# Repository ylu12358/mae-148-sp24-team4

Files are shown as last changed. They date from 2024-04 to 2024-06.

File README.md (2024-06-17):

# MAE 148 SP24 Team 4

## Premise
SortBot is an autonomous vehicle that delivers items from one pickup point to different drop off locations.

## CAD
All parts modeled in Solidworks

## Schematic
Generated using LaTeX
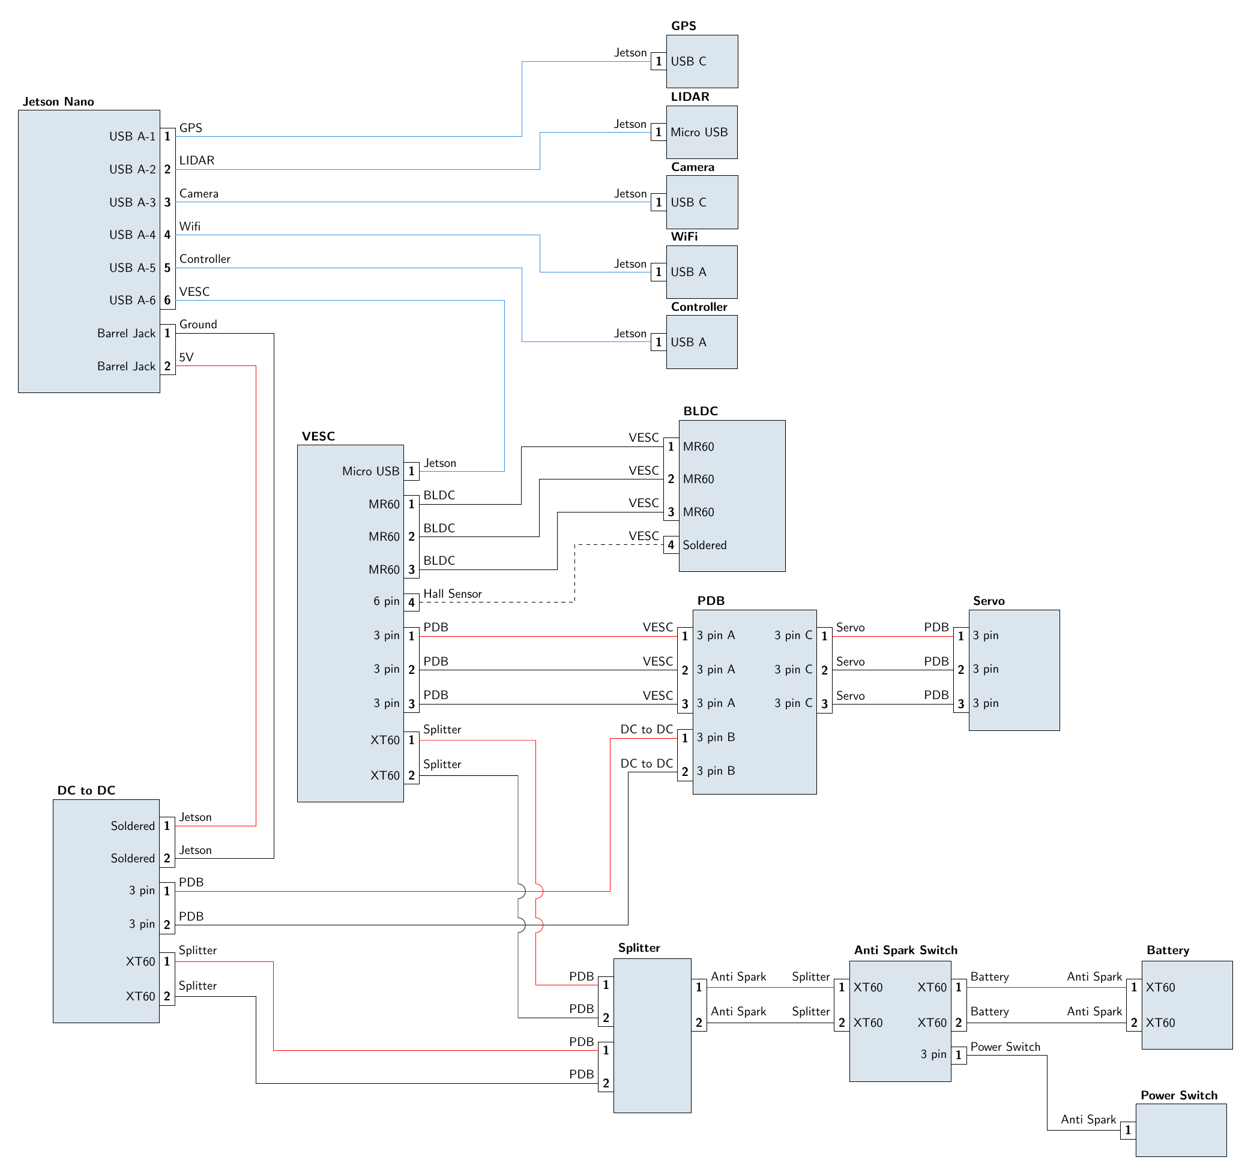
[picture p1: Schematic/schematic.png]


## Software
Shape detection AI model
Path optimization
GPS navigation

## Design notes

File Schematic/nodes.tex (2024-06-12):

\documentclass[border=5mm]{standalone}
\usepackage{tikz}
\usetikzlibrary{calc}           % For general calculations
\usetikzlibrary{matrix}         % For the matrix cmd
\usetikzlibrary{positioning}    % For above = Xcm of and similars
\usetikzlibrary{intersections}  % Mainly here for the arc over line
\usetikzlibrary{topaths}        % Enable move to operation
\usetikzlibrary{backgrounds}    % Put colors in background
\usetikzlibrary{shapes}         % Allow use of more shapes

\tikzset{rosnode/.style={ellipse,
                        fill=blue!20,
                        matrix of nodes,
                        row sep=1mm,
                        column sep=1mm,
                        nodes={anchor=center, inner sep=0pt, outer sep=0pt}
                        },
        rostopic/.style={ellipse,
                        fill=blue!50,
                        matrix of nodes,
                        row sep=1mm,
                        column sep=1mm,
                        nodes={anchor=center, inner sep=0pt, outer sep=0pt}
        },
}

\begin{document}
\sffamily

\begin{tikzpicture}
    [scale=.9,auto=center]

    % EXAMPLE
    \matrix[rosnode] (exampleA) {
        exampleA node \\
    };

    \matrix[rostopic, right= of exampleA] (exampleC) {
        example topic \\
    };

    \matrix[rosnode, right= of exampleC] (exampleB) {
        exampleB node \\
    };
    
    \draw[->,orange,line width=1pt] (exampleA) -- (exampleC);
    \draw[->,green,line width=1pt] (exampleC) -- (exampleB);

    % NODE DIAGRAM
    \matrix[rosnode, below right= 5cm of exampleC] (detection) {
        detection node \\
        \parbox{3.6cm}{Detects shapes, spits out a string corresponding to which dropoff locations need to be visited} \\
    };

    \matrix[rostopic, below= of detection] (dropoff) {
        dropoff topic \\
        String of dropoff locations \\
    };

    \matrix[rosnode, below= of dropoff] (pathCreation) {
        pathCreation node \\
    };

    \matrix[rostopic, below left= of pathCreation] (path) {
        path topic \\
        \parbox{3cm}{Contains csv file of GPS coordinates} \\
    };

    \matrix[rostopic, right= of path] (status) {
        status topic \\
        \parbox{4cm}{Contains or doesn't contain signal that path creation is done} \\
    };

    \matrix[rosnode, below= of status] (donkeyProcessing) {
        donkeyProcessing node \\
        \parbox{4cm}{Starts donkeycar, resets the origin, sets mode to autosteer only} \\
    };

    \matrix[rosnode, left= of donkeyProcessing] (donkeycar) {
        donkeycar "node" \\
        Good ole donkeycar \\
    };

    \matrix[rosnode, left= of donkeycar] (throttleProcessing) {
        throttleProcessing node \\
        \parbox{4.5cm}{Takes in GPS data, calculates distance from current position to next dropoff point, sets donkeycar to either full auto or steering only (off)} \\
    };

    \matrix[rostopic, above= of throttleProcessing] (GPSdata) {
        GPSdata topic \\
        Reports current GPS data \\
    };

    \matrix[rosnode, above= of GPSdata] (GPS) {
        GPS node \\
        \parbox{4cm}{Spits out serial data from GPS} \\
    };
    
    \draw[->,orange,line width=1pt] (detection) -- (dropoff);
    \draw[->,green,line width=1pt] (dropoff) -- (pathCreation);
    \draw[->,orange,line width=1pt] (pathCreation) -- (path);
    \draw[->,orange,line width=1pt] (pathCreation) -- (status);
    \draw[->,green,line width=1pt] (status) -- (donkeyProcessing);

    \draw[->,blue,line width=1pt] (path) -- (donkeycar);
    \draw[->,blue,line width=1pt] (donkeyProcessing) -- (donkeycar);
    \draw[->,blue,line width=1pt] (throttleProcessing) -- (donkeycar);

    \draw[->,orange,line width=1pt] (GPS) -- (GPSdata);
    \draw[->,green,line width=1pt] (GPSdata) -- (throttleProcessing);
    \draw[->,green,line width=1pt] (path) -- (throttleProcessing);
    
\end{tikzpicture}
\end{document}

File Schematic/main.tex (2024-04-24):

\documentclass[border=5mm]{standalone}
\usepackage{tikz}
\usetikzlibrary{calc}           % For general calculations
\usetikzlibrary{matrix}         % For the matrix cmd
\usetikzlibrary{positioning}    % For above = Xcm of and similars
\usetikzlibrary{intersections}  % Mainly here for the arc over line
\usetikzlibrary{topaths}        % Enable move to operation
\usetikzlibrary{backgrounds}    % Put colors in background

%%% Sourced from https://tex.stackexchange.com/questions/241357/wiring-diagrams-with-pinout
%%% Adapted from https://tex.stackexchange.com/a/111674/114143
%%% provides syntax for jumping lines
\tikzset{
    connect/.style args={(#1) to (#2) over #3 by #4}{
        insert path={
            \pgfextra{
                \pgfinterruptpath
                    \path [name path=userpath] (#1) -- (#2);
                    \path [name intersections={of=userpath and #3,by=overpoint}];
                \endpgfinterruptpath                
            }
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
                                       column 2/.style={font=\bfseries}
                                       },
        camera/.style={column 1/.style={nodes={above left}},
                                       column 3/.style={nodes={right}},
                                       column 2/.style={font=\bfseries}
                                       },
        wifi/.style={column 1/.style={nodes={above left}},
                                       column 3/.style={nodes={right}},
                                       column 2/.style={font=\bfseries}
                                       },
        controller/.style={column 1/.style={nodes={above left}},
                                       column 3/.style={nodes={right}},
                                       column 2/.style={font=\bfseries}
                                       },
        vesc/.style={column 1/.style={nodes={left}},
                                       column 3/.style={nodes={above right}},
                                       column 2/.style={font=\bfseries}
                                       },
        pdbL/.style={column 1/.style={nodes={above left}},
                                       column 3/.style={nodes={right}},
                                       column 2/.style={font=\bfseries}
                                       },
        pdbR/.style={column 1/.style={nodes={left}},
                                       column 3/.style={nodes={above right}},
                                       column 2/.style={font=\bfseries}
                                       },
        bldc/.style={column 1/.style={nodes={above left}},
                                       column 3/.style={nodes={right}},
                                       column 2/.style={font=\bfseries}
                                       },
        dc2dc/.style={column 1/.style={nodes={left}},
                                       column 3/.style={nodes={above right}},
                                       column 2/.style={font=\bfseries}
                                       },
        splitterL/.style={column 1/.style={nodes={above left}},
                                       column 3/.style={nodes={right}},
                                       column 2/.style={font=\bfseries}
                                       },
        splitterR/.style={column 1/.style={nodes={left}},
                                       column 3/.style={nodes={above right}},
                                       column 2/.style={font=\bfseries}
                                       },
        antisparkL/.style={column 1/.style={nodes={above left}},
                                       column 3/.style={nodes={right}},
                                       column 2/.style={font=\bfseries}
                                       },
        antisparkR/.style={column 1/.style={nodes={left}},
                                       column 3/.style={nodes={above right}},
                                       column 2/.style={font=\bfseries}
                                       },
        servo/.style={column 1/.style={nodes={above left}},
                                       column 3/.style={nodes={right}},
                                       column 2/.style={font=\bfseries}
                                       },
        battery/.style={column 1/.style={nodes={above left}},
                                       column 3/.style={nodes={right}},
                                       column 2/.style={font=\bfseries}
                                       },
        power/.style={column 1/.style={nodes={above left}},
                                       column 3/.style={nodes={right}},
                                       column 2/.style={font=\bfseries}
                                       },
}

%% Colors
\definecolor{beaublue}{rgb}{0.86, 0.9, 0.93}
\definecolor{usbblue}{rgb}{0.19, 0.55, 0.91}

\begin{document}
\sffamily
\begin{tikzpicture}
%% Drawing the first block (jetson)
    \matrix[wire board,jetson] (jetson) {
        USB A-1     &   1   &   GPS         \\
        USB A-2     &   2   &   LIDAR       \\
        USB A-3     &   3   &   Camera      \\
        USB A-4     &   4   &   Wifi        \\
        USB A-5     &   5   &   Controller  \\
        USB A-6     &   6   &   VESC        \\
        Barrel Jack &   1   &   Ground      \\
        Barrel Jack &   2   &   5V          \\
    };
    \draw (jetson-1-2.north east) rectangle (jetson-6-2.south west); % USB
    \draw (jetson-7-2.north east) rectangle (jetson-8-2.south west); % Barrel Jack
    \scoped[on background layer]{\draw [fill=beaublue] (jetson-1-2.north west)+(-4cm,0.5cm) node[above right, font=\bfseries]{Jetson Nano} rectangle ($(jetson-8-2.south west)+(0,-0.5cm)$);}

%% GPS
    \matrix[wire board, gps, matrix anchor=south, above right=1.151cm and 14cm of jetson.north] (gps) {
        Jetson  &   1   &   USB C \\
    };
    \draw (gps-1-2.north east) rectangle (gps-1-2.south west); % USB
    \scoped[on background layer]{\draw [fill=beaublue] (gps-1-2.north east)+(0cm,0.5cm) node[above right, align=center, font=\bfseries]{GPS} rectangle ($(gps-1-2.south east)+(2cm,-0.5cm)$);}

%% LIDAR
    \matrix[wire board, lidar, matrix anchor=south, below right=2cm and 0.3cm of gps.south] (lidar) {
        Jetson  &   1   &   Micro USB \\
    };
    \draw (lidar-1-2.north east) rectangle (lidar-1-2.south west); % USB
    \scoped[on background layer]{\draw [fill=beaublue] (lidar-1-2.north east)+(0cm,0.5cm) node[above right, align=center, font=\bfseries]{LIDAR} rectangle ($(lidar-1-2.south east)+(2cm,-0.5cm)$);}

%% Camera
    \matrix[wire board, camera, matrix anchor=north, below left=1cm and 0.3cm of lidar.south] (camera) {
        Jetson  &   1   &   USB C \\
    };
    \draw (camera-1-2.north east) rectangle (camera-1-2.south west); % USB
    \scoped[on background layer]{\draw [fill=beaublue] (camera-1-2.north east)+(0cm,0.5cm) node[above right, align=center, font=\bfseries]{Camera} rectangle ($(camera-1-2.south east)+(2cm,-0.5cm)$);}

%% Wifi
    \matrix[wire board, wifi, matrix anchor=north, below=1cm of camera.south] (wifi) {
        Jetson  &   1   &   USB A \\
    };
    \draw (wifi-1-2.north east) rectangle (wifi-1-2.south west); % USB
    \scoped[on background layer]{\draw [fill=beaublue] (wifi-1-2.north east)+(0cm,0.5cm) node[above right, align=center, font=\bfseries]{WiFi} rectangle ($(wifi-1-2.south east)+(2cm,-0.5cm)$);}

%% Controller
    \matrix[wire board, controller, matrix anchor=north, below=1cm of wifi.south] (controller) {
        Jetson  &   1   &   USB A \\
    };
    \draw (controller-1-2.north east) rectangle (controller-1-2.south west); % USB
    \scoped[on background layer]{\draw [fill=beaublue] (controller-1-2.north east)+(0cm,0.5cm) node[above right, align=center, font=\bfseries]{Controller} rectangle ($(controller-1-2.south east)+(2cm,-0.5cm)$);}

%% VESC
    \matrix[wire board, vesc, matrix anchor=north, below right=2cm and 7cm of jetson.south] (vesc) {
        Micro USB   &   1   &   Jetson      \\
        MR60        &   1   &   BLDC        \\
        MR60        &   2   &   BLDC        \\
        MR60        &   3   &   BLDC        \\
        6 pin       &   4   &   Hall Sensor \\
        3 pin       &   1   &   PDB         \\
        3 pin       &   2   &   PDB         \\
        3 pin       &   3   &   PDB         \\
        XT60        &   1   &   Splitter    \\
        XT60        &   2   &   Splitter    \\
    };
    \draw (vesc-1-2.north east) rectangle (vesc-1-2.south west); % USB
    \draw (vesc-2-2.north east) rectangle (vesc-4-2.south west); % BLDC
    \draw (vesc-5-2.north east) rectangle (vesc-5-2.south west); % Hall Sensor
    \draw (vesc-6-2.north east) rectangle (vesc-8-2.south west); % PDB
    \draw (vesc-9-2.north east) rectangle (vesc-10-2.south west); % splitterL
    \scoped[on background layer]{\draw [fill=beaublue] (vesc-1-2.north west)+(-3cm,0.5cm) node[above right, align=center, font=\bfseries]{VESC} rectangle ($(vesc-10-2.south west)+(0cm,-0.5cm)$);}

%% BLDC
    \matrix[wire board, bldc, matrix anchor=north, above right=.7cm and 7.5cm of vesc.north] (bldc) {
        VESC  &   1   & MR60        \\
        VESC  &   2   & MR60        \\
        VESC  &   3   & MR60        \\
        VESC  &   4   & Soldered    \\
    };
    \draw (bldc-1-2.north east) rectangle (bldc-3-2.south west); % VESC
    \draw (bldc-4-2.north east) rectangle (bldc-4-2.south west); % Hall Sensor
    \scoped[on background layer]{\draw [fill=beaublue] (bldc-1-2.north east)+(0cm,0.5cm) node[above right, align=center, font=\bfseries]{BLDC} rectangle ($(bldc-4-2.south east)+(3cm,-0.5cm)$);}

%% PDB
    \matrix[wire board, pdbL, matrix anchor=north, below=1.6069cm of bldc.south] (pdbL) {
        VESC        &   1   &   3 pin A \\
        VESC        &   2   &   3 pin A \\
        VESC        &   3   &   3 pin A \\
        DC to DC    &   1   &   3 pin B \\
        DC to DC    &   2   &   3 pin B \\
    };
    \matrix[wire board, pdbR, matrix anchor=north, right=4cm of pdbL.north] (pdbR) {
        3 pin C &   1   &   Servo   \\
        3 pin C &   2   &   Servo   \\
        3 pin C &   3   &   Servo   \\
    };
    \draw (pdbL-1-2.north east) rectangle (pdbL-3-2.south west); % VESC
    \draw (pdbL-4-2.north east) rectangle (pdbL-5-2.south west); % DC to DC
    \draw (pdbR-1-2.north east) rectangle (pdbR-3-2.south west); % Servo
    \scoped[on background layer]{\draw [fill=beaublue] (pdbL-1-2.north east)+(0cm,0.5cm) node[above right, align=center, font=\bfseries]{PDB} rectangle ($(pdbR-3-2.south west)+(0cm,-2.3cm)$);}

%% Servo
    \matrix[wire board, servo, matrix anchor=north, right=4cm of pdbR.north] (servo) {
        PDB     &   1   &   3 pin   \\
        PDB     &   2   &   3 pin   \\
        PDB     &   3   &   3 pin   \\
    };
    \draw (servo-1-2.north east) rectangle (servo-3-2.south west); % PDB
    \scoped[on background layer]{\draw [fill=beaublue] (servo-1-2.north east)+(0cm,0.5cm) node[above right, align=center, font=\bfseries]{Servo} rectangle ($(servo-3-2.south west)+(3cm,-0.5cm)$);}

%% DC to DC
    \matrix[wire board, dc2dc, matrix anchor=north, below=12cm of jetson.south] (dc2dc) {
        Soldered    &   1   &   Jetson      \\
        Soldered    &   2   &   Jetson      \\
        3 pin       &   1   &   PDB         \\
        3 pin       &   2   &   PDB         \\
        XT60        &   1   &   Splitter    \\
        XT60        &   2   &   Splitter    \\
    };
    \draw (dc2dc-1-2.north east) rectangle (dc2dc-2-2.south west); % Jetson
    \draw (dc2dc-3-2.north east) rectangle (dc2dc-4-2.south west); % splitterL
    \draw (dc2dc-5-2.north east) rectangle (dc2dc-6-2.south west); % PDB
    \scoped[on background layer]{\draw [fill=beaublue] (dc2dc-1-2.north west)+(-3cm,0.5cm) node[above right, align=center, font=\bfseries]{DC to DC} rectangle ($(dc2dc-6-2.south west)+(0cm,-0.5cm)$);}

%% Splitter
    \matrix[wire board, splitterL, matrix anchor=north, below left=5cm and 2.5cm of pdbL.south] (splitterL) {
        PDB     &   1   &   \\
        PDB     &   2   &   \\
        PDB     &   1   &   \\
        PDB     &   2   &   \\
    };
    \matrix[wire board, splitterR, matrix anchor=north, right=4cm of splitterL.north] (splitterR) {
                &   1   &   Anti Spark  \\
                &   2   &   Anti Spark  \\
    };
    \draw (splitterL-1-2.north east) rectangle (splitterL-2-2.south west); % VESC
    \draw (splitterL-3-2.north east) rectangle (splitterL-4-2.south west); % DC to DC
    \draw (splitterR-1-2.north east) rectangle (splitterR-2-2.south west); % Anti Spark
    \scoped[on background layer]{\draw [fill=beaublue] (splitterL-1-2.north east)+(0cm,0.5cm) node[above right, align=center, font=\bfseries]{Splitter} rectangle ($(splitterR-2-2.south west)+(0cm,-2.3cm)$);}

%% Anti Spark Switch
    \matrix[wire board, antisparkL, matrix anchor=north, right=3cm of splitterR.north] (antisparkL) {
        Splitter    &   1   &   XT60    \\
        Splitter    &   2   &   XT60    \\
    };
    \matrix[wire board, antisparkR, matrix anchor=north, right=4cm of antisparkL.north] (antisparkR) {
        XT60    &   1   &   Battery         \\
        XT60    &   2   &   Battery         \\
        3 pin   &   1   &   Power Switch    \\
    };
    \draw (antisparkL-1-2.north east) rectangle (antisparkL-2-2.south west); % Splitter
    \draw (antisparkR-1-2.north east) rectangle (antisparkR-2-2.south west); % Battery
    \draw (antisparkR-3-2.north east) rectangle (antisparkR-3-2.south west); % Power Switch
    \scoped[on background layer]{\draw [fill=beaublue] (antisparkL-1-2.north east)+(0cm,0.5cm) node[above right, align=center, font=\bfseries]{Anti Spark Switch} rectangle ($(antisparkR-3-2.south west)+(0cm,-0.5cm)$)};

%% Battery
    \matrix[wire board, battery, matrix anchor=north, right=4cm of antisparkR.north] (battery) {
        Anti Spark    &   1   &   XT60    \\
        Anti Spark    &   2   &   XT60    \\
    };
    \draw (battery-1-2.north east) rectangle (battery-2-2.south west); % Anti Spark
    \scoped[on background layer]{\draw [fill=beaublue] (battery-1-2.north east)+(0cm,0.5cm) node[above right, align=center, font=\bfseries]{Battery} rectangle ($(battery-2-2.south west)+(3cm,-0.5cm)$);}

%% Power Switch
    \matrix[wire board, power, matrix anchor=north, below left=2cm and .7cm of battery.south] (power) {
        Anti Spark    &   1   &     \\
    };
    \draw (power-1-2.north east) rectangle (power-1-2.south west); % Anti Spark
    \scoped[on background layer]{\draw [fill=beaublue] (power-1-2.north east)+(0cm,0.5cm) node[above right, align=center, font=\bfseries]{Power Switch} rectangle ($(power-1-2.south west)+(3cm,-0.5cm)$);}

%% Wires
    \draw [usbblue] (jetson-1-2) -- +(10.0cm,0) |- (gps-1-2);
    \draw [usbblue] (jetson-2-2) -- +(10.5cm,0) |- (lidar-1-2);
    \draw [usbblue] (jetson-3-2) -- +(10.5cm,0) |- (camera-1-2);
    \draw [usbblue] (jetson-4-2) -- +(10.5cm,0) |- (wifi-1-2);
    \draw [usbblue] (jetson-5-2) -- +(10.0cm,0) |- (controller-1-2);
    
    \draw [usbblue] (jetson-6-2) -- +(9.5cm,0) |- (vesc-1-2);

    \draw (jetson-7-2) -- +(3.0cm,0) |- (dc2dc-2-2);
    \draw [red] (jetson-8-2) -- +(2.5cm,0) |- (dc2dc-1-2);
    
    \draw (vesc-2-2) -- +(3.1cm,0) |- (bldc-1-2);
    \draw (vesc-3-2) -- +(3.6cm,0) |- (bldc-2-2);
    \draw (vesc-4-2) -- +(4.1cm,0) |- (bldc-3-2);
    \draw [dashed] (vesc-5-2) -- +(4.6cm,0) |- (bldc-4-2);

    \draw [red] (vesc-6-2) -- +(4.5cm,0) |- (pdbL-1-2);
    \draw (vesc-7-2) -- +(4.0cm,0) |- (pdbL-2-2);
    \draw (vesc-8-2) -- +(3.5cm,0) |- (pdbL-3-2);

    \draw [red] [name path=horiz1] (dc2dc-3-2) -- +(12.5cm,0) |- (pdbL-4-2);
    \draw [name path=horiz2] (dc2dc-4-2) -- +(13.0cm,0) |- (pdbL-5-2);
    
    \draw [red] (pdbR-1-2) -- +(0.5cm,0) |- (servo-1-2);
    \draw (pdbR-2-2) -- +(0.5cm,0) |- (servo-2-2);
    \draw (pdbR-3-2) -- +(0.5cm,0) |- (servo-3-2);

    \path [name path=over1](vesc-9-2) -- +(3.5cm,0) node[coordinate](A1){} |- node[pos=.34,coordinate](A2){} node[coordinate](A3){} (splitterL-1-2);
    \draw [red] [connect={(A1) to (A2) over horiz1 by -6pt}] (vesc-9-2) -- (A1);
    \draw [red] [connect={(A2) to (A3) over horiz2 by -6pt}] (A3) -- (splitterL-1-2);
    
    \path [name path=over1](vesc-10-2) -- +(3.0cm,0) node[coordinate](B1){} |- node[pos=.29,coordinate](B2){} node[coordinate](B3){} (splitterL-2-2);
    \draw [connect={(B1) to (B2) over horiz1 by -6pt}] (vesc-10-2) -- (B1);
    \draw [connect={(B2) to (B3) over horiz2 by -6pt}] (B3) -- (splitterL-2-2);
    
    \draw [red] (dc2dc-5-2) -- +(3.0cm,0) |- (splitterL-3-2);
    \draw (dc2dc-6-2) -- +(2.5cm,0) |- (splitterL-4-2);

    \draw [red] (splitterR-1-2) -- +(0.5cm,0) |- (antisparkL-1-2);
    \draw (splitterR-2-2) -- +(0.5cm,0) |- (antisparkL-2-2);

    \draw [red](antisparkR-1-2) -- +(0.5cm,0) |- (battery-1-2);
    \draw (antisparkR-2-2) -- +(0.5cm,0) |- (battery-2-2);
    \draw (antisparkR-3-2) -- +(2.5cm,0) |- (power-1-2);

\end{tikzpicture}                                          
\end{document}

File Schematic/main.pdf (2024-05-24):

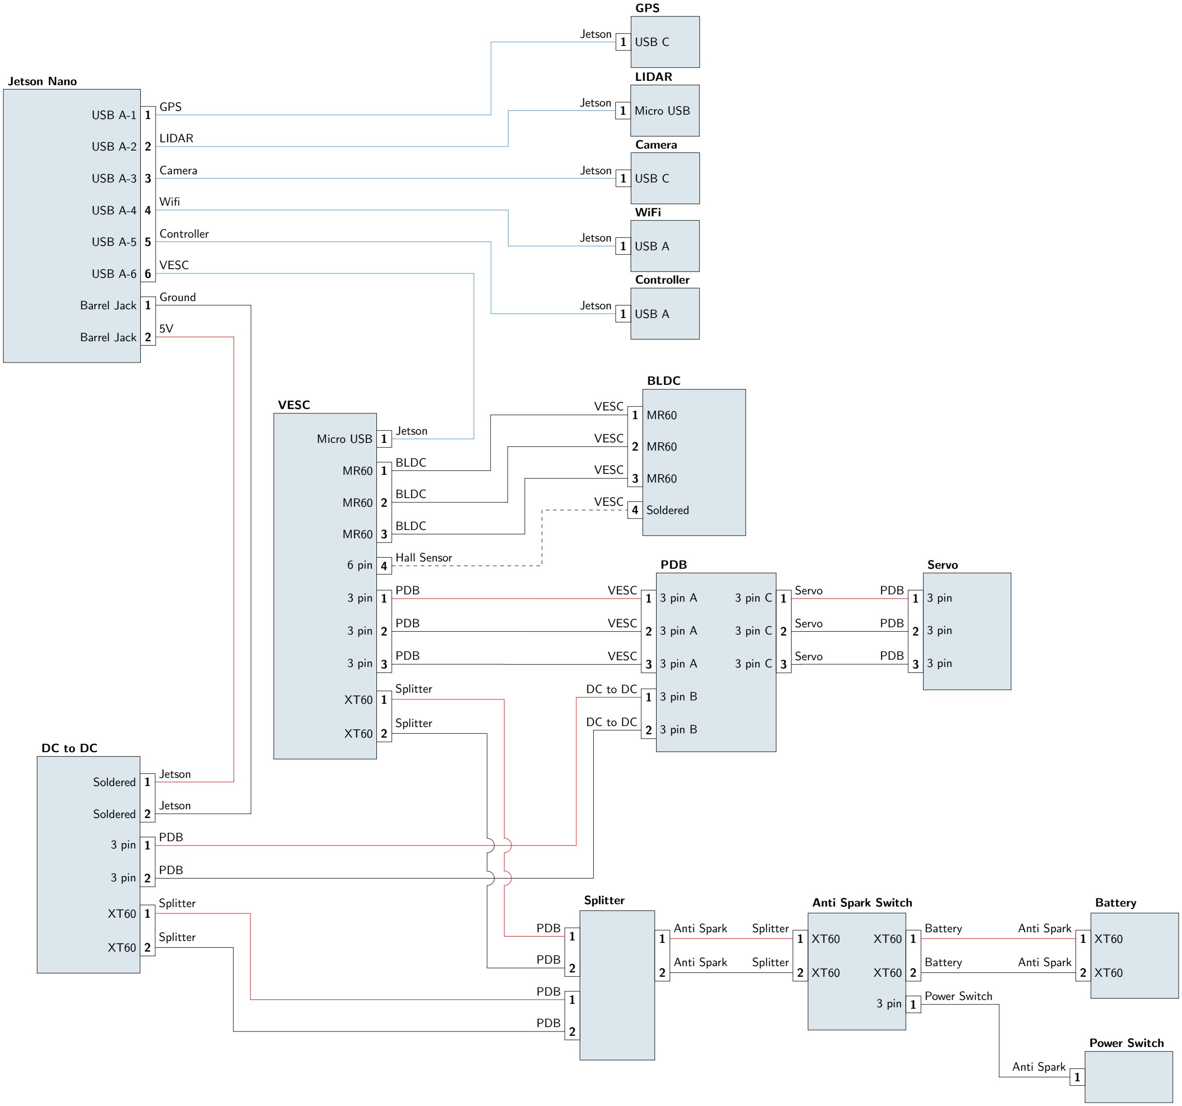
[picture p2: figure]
Jetson Nano; GPS; LIDAR; Camera; WiFi; Controller; VESC; BLDC; PDB; Servo; Splitter; Anti Spark Switch; Battery; Power Switch; USB A-1; USB A-2; USB A-3; USB A-4; Wifi; USB A-5; USB A-6; Barrel Jack; Ground; Jetson; USB C; Micro USB; USB A; 6 pin; Hall Sensor; 3 pin; 4 Soldered; 3 pin A; 3 pin B; 3 pin C; Soldered; Anti Spark

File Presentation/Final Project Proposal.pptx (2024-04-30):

## Project Proposal

- ECE MAE 148 Team 4| April 30, 2024

Yuanyang Lu, Miles Puchner, Alex La, David Deharo

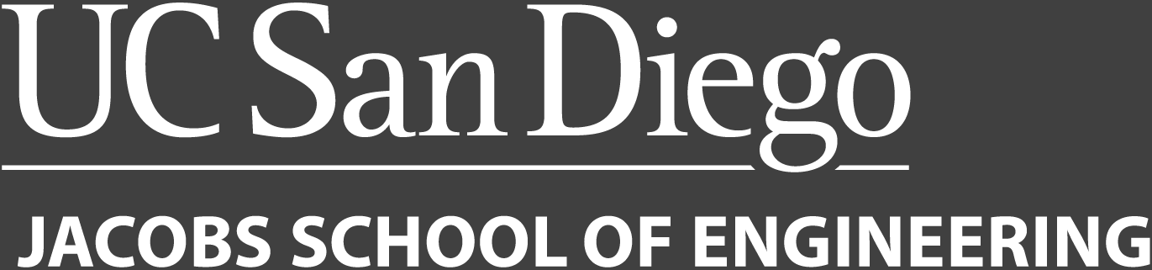
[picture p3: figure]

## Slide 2

ECE MAE 148 Team 4

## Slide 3

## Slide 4

## Thank you!

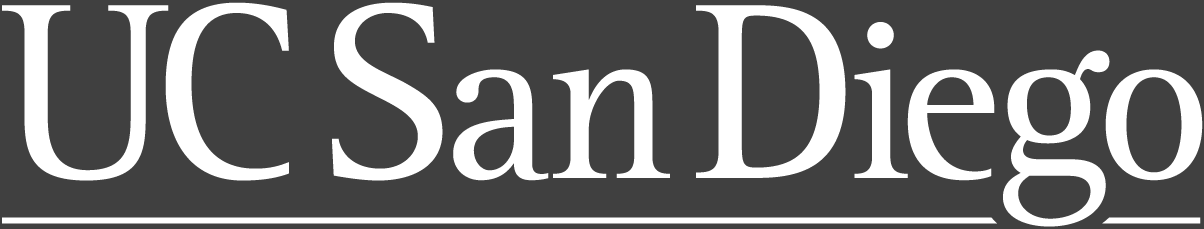
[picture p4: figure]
UC San Diego Logo

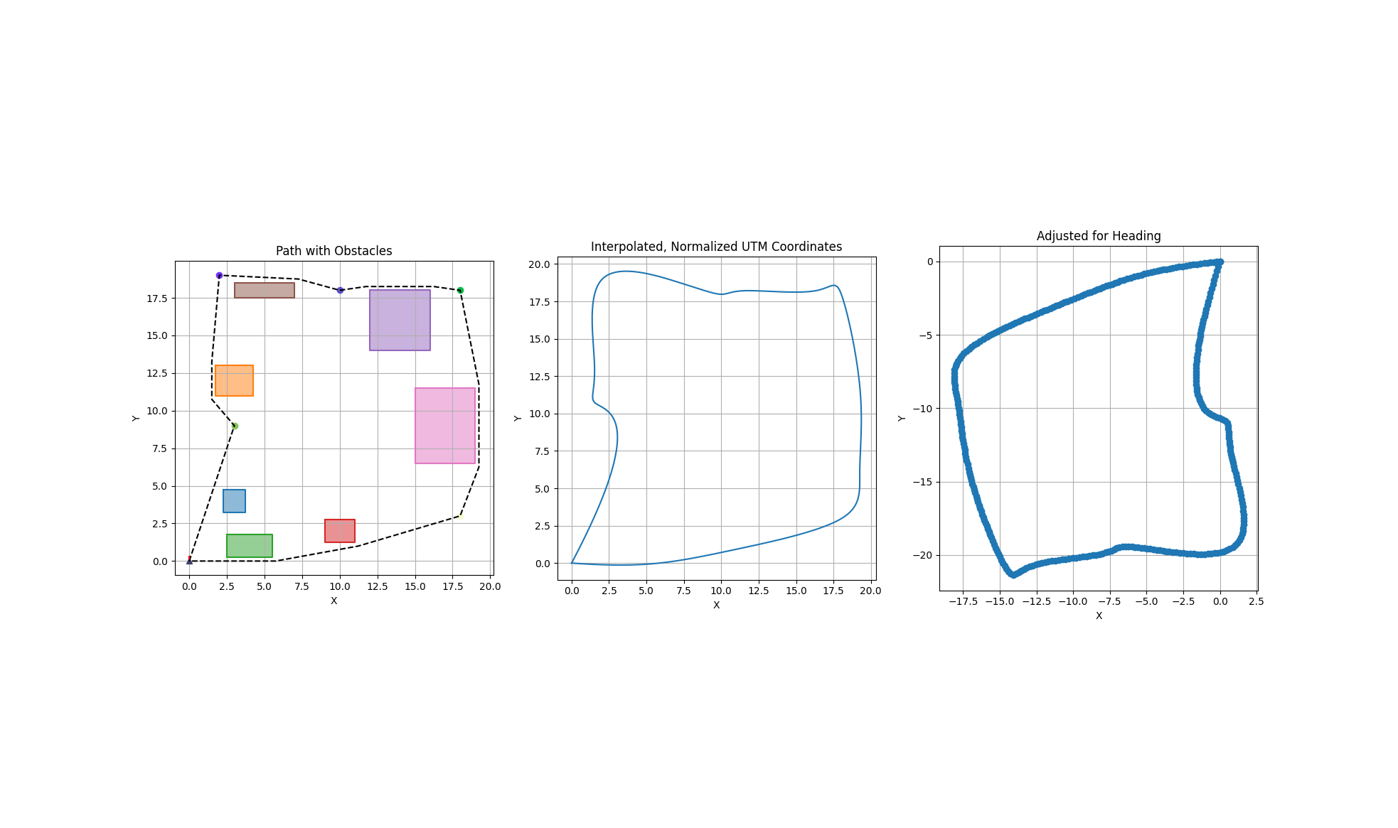
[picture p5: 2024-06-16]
Presentation/Figure_3.png

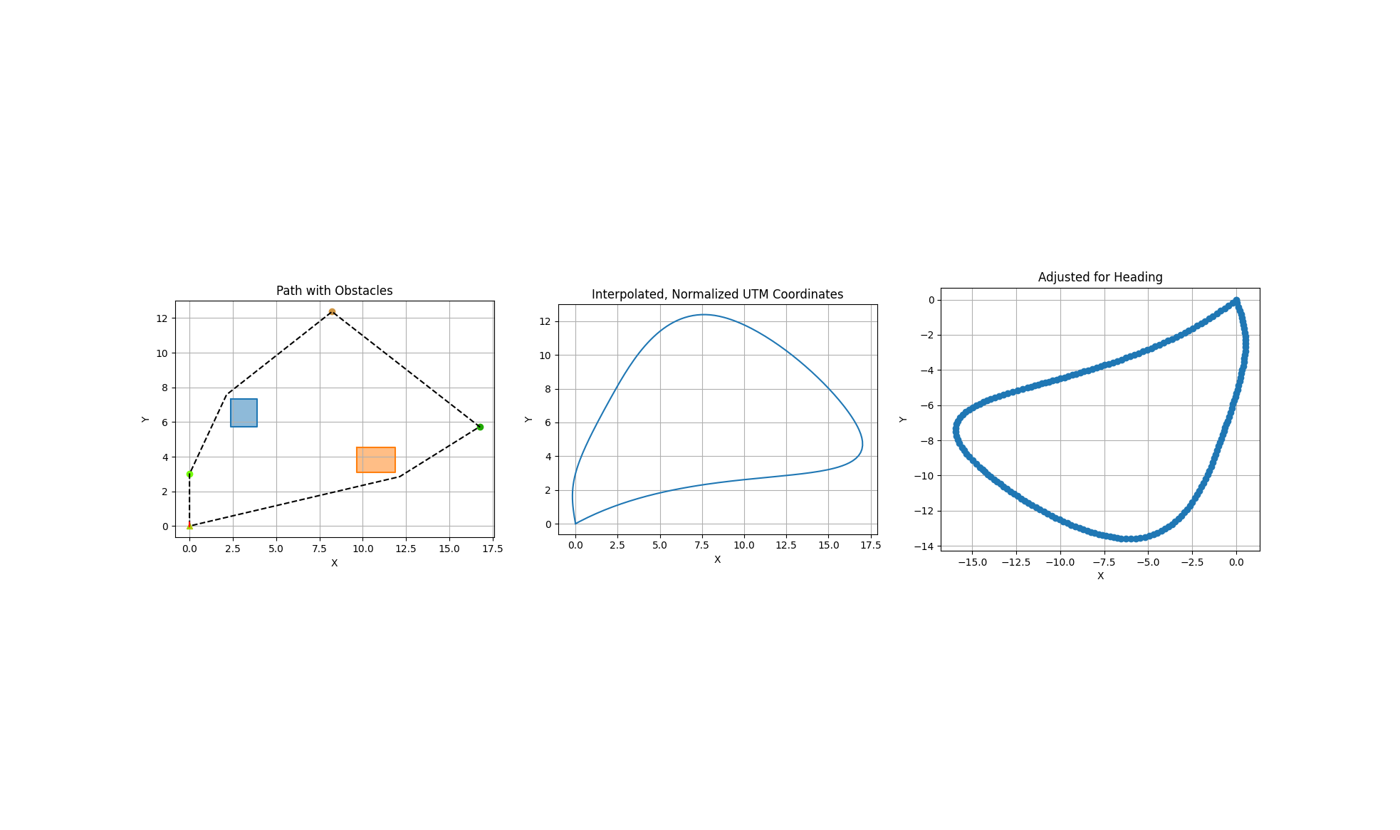
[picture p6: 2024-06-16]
Presentation/Figure_2.png

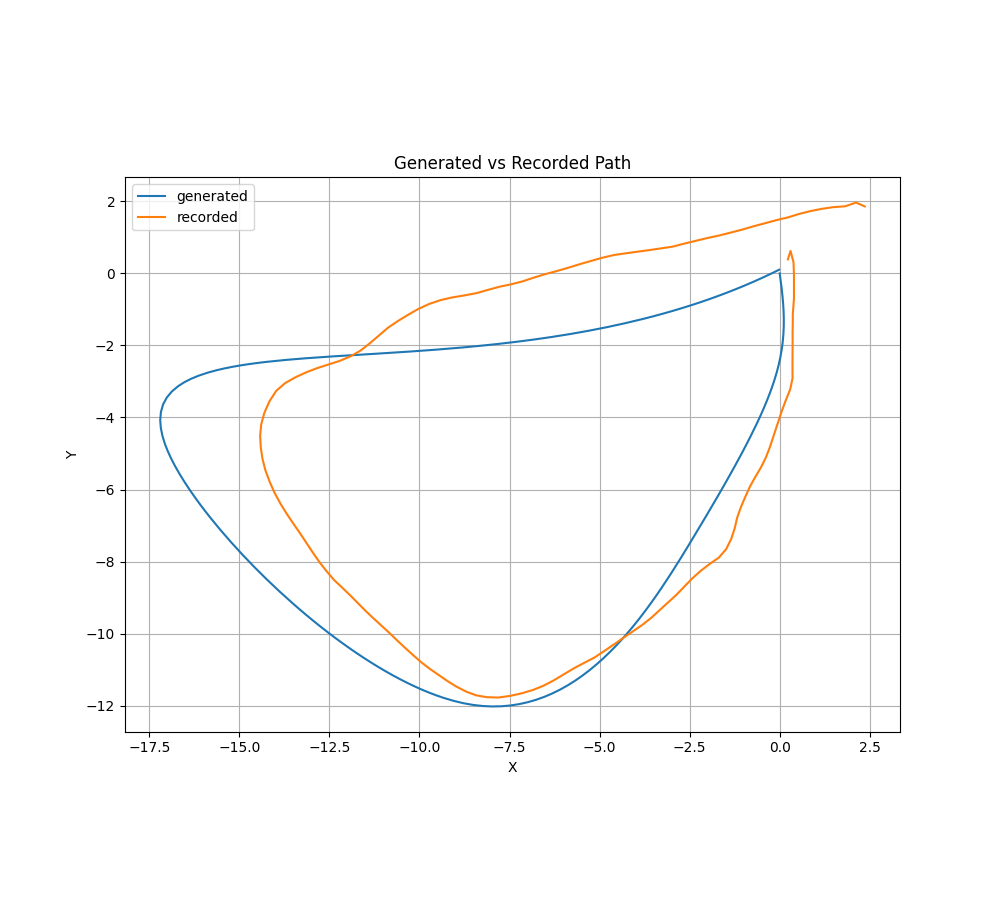
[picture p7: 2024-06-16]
Presentation/Figure_1.png

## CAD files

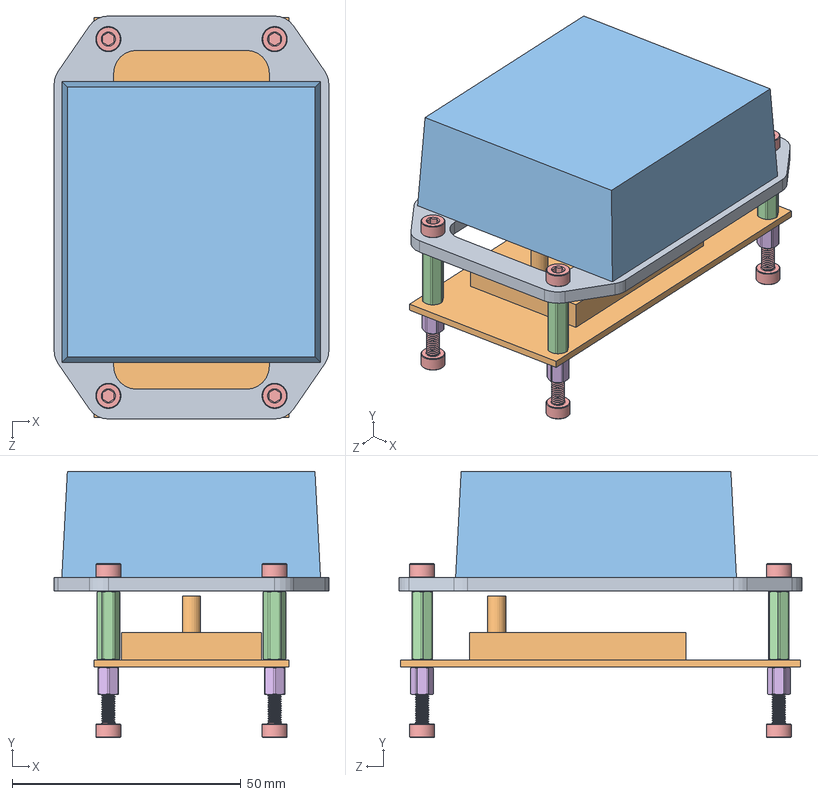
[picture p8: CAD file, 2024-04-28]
CAD/GPS/GPS Assembly.SLDASM
60.0 x 58.1 x 88.0 mm
GPS Bracket
GPS
GPS Antenna
94868A722_Female Threaded Hex Standoff x 4
91290A113_Alloy Steel Socket Head Screw x 8
93655A093_Male-Female Threaded Hex Standoff x 4

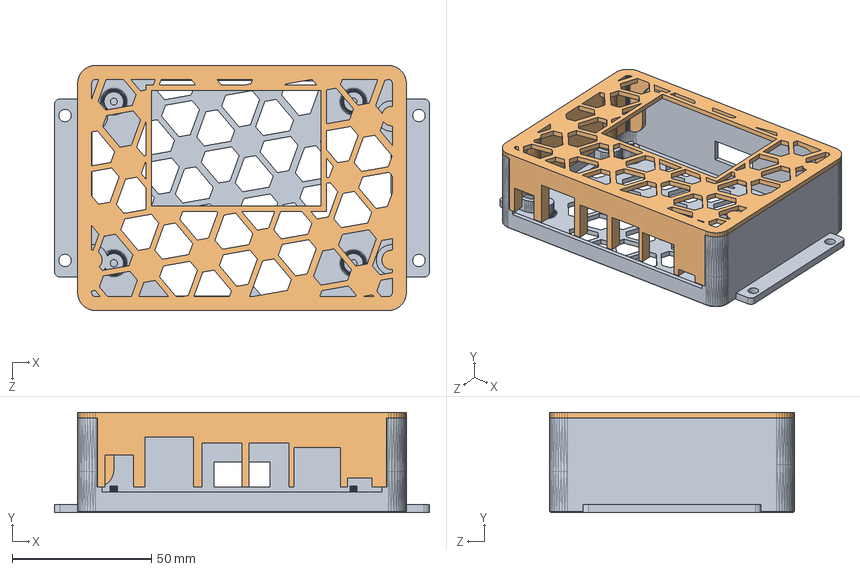
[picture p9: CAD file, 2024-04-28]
CAD/Jetson/Jetson.SLDASM
134.6 x 36.0 x 88.0 mm
Case Bottom
Case Top

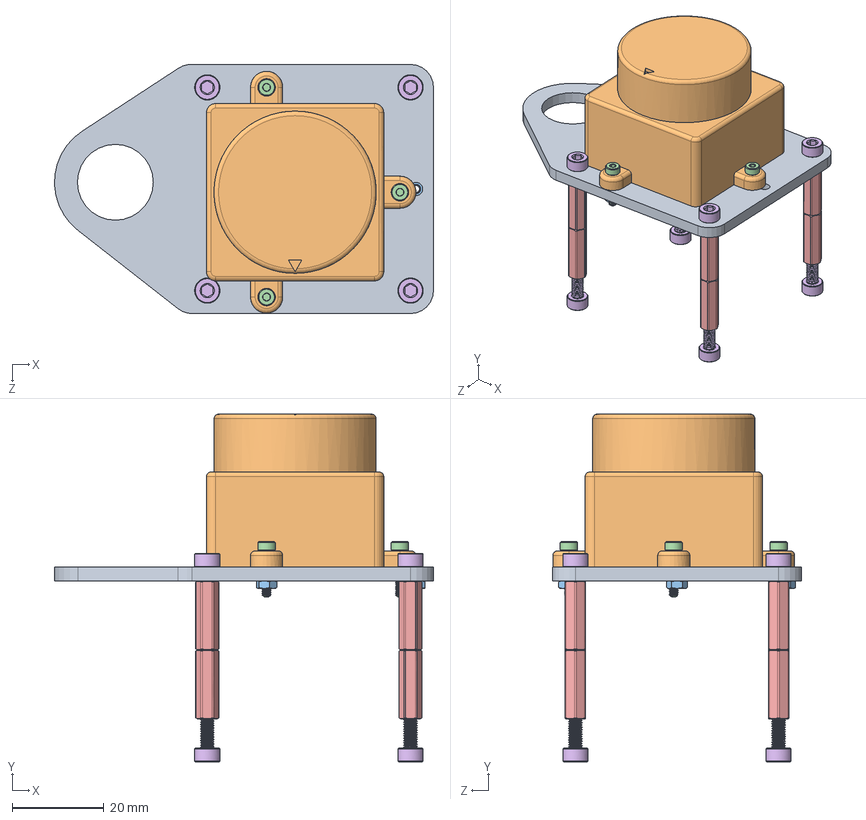
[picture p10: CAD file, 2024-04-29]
CAD/LIDAR/LIDAR Assembly.SLDASM
82.4 x 75.7 x 54.2 mm
LIDAR Mount
LIDAR
90591A265_Zinc-Plated Steel Hex Nut x 3
91292A833_18-8 Stainless Steel Socket Head Screw x 3
94868A722_Female Threaded Hex Standoff (1) x 8
91290A113_Alloy Steel Socket Head Screw x 8

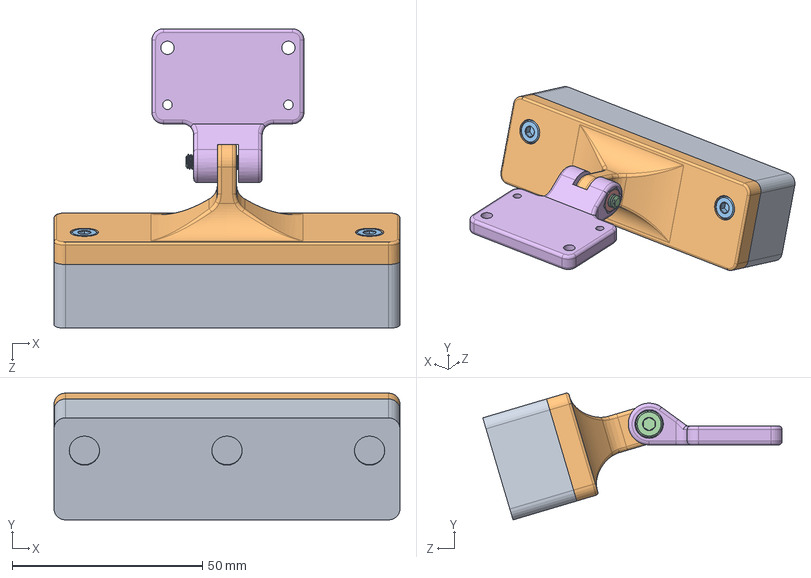
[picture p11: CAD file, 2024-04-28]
CAD/Camera/Camera Assembly.SLDASM
91.0 x 33.4 x 78.8 mm
Oak D Lite
Camera Mount Plate
91292A108_18-8 Stainless Steel Socket Head Screw x 2
91292A118_18-8 Stainless Steel Socket Head Screw
90592A090_Steel Hex Nut
Camera Mount Base 2

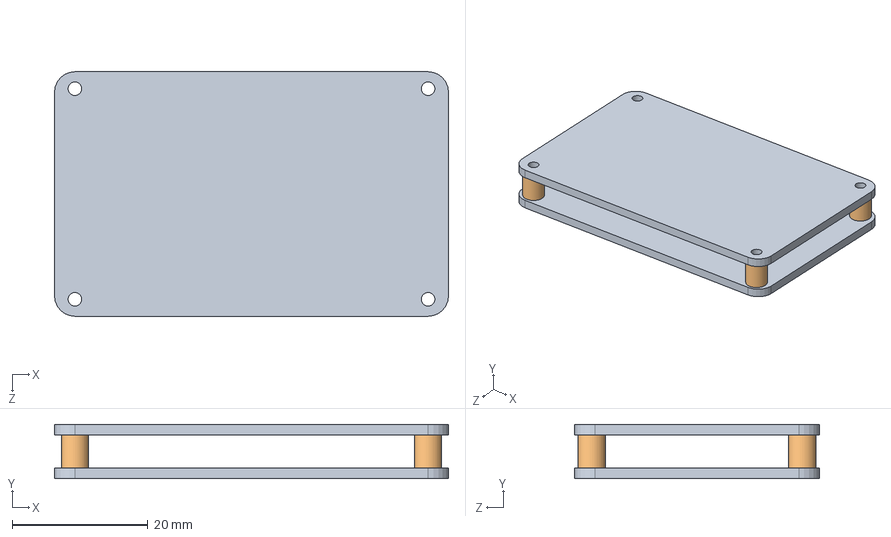
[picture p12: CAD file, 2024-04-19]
CAD/DC to DC/DC to DC.SLDASM
58.0 x 8.00 x 36.0 mm
DC to DC PCB x 2
DC to DC Standoff x 4

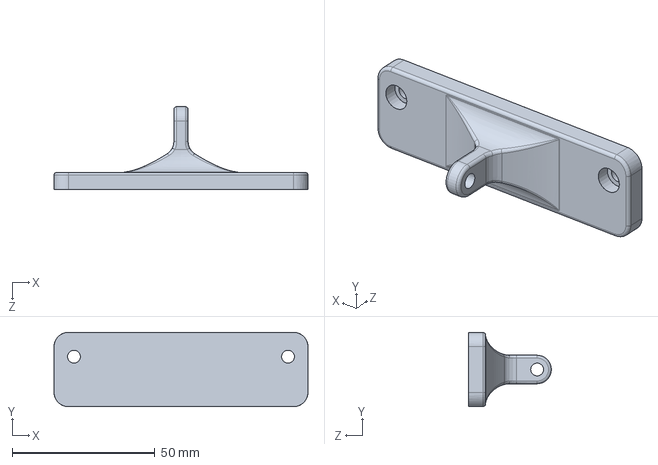
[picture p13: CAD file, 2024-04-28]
CAD/Camera/Camera Mount Plate.SLDPRT
89.0 x 26.0 x 29.0 mm

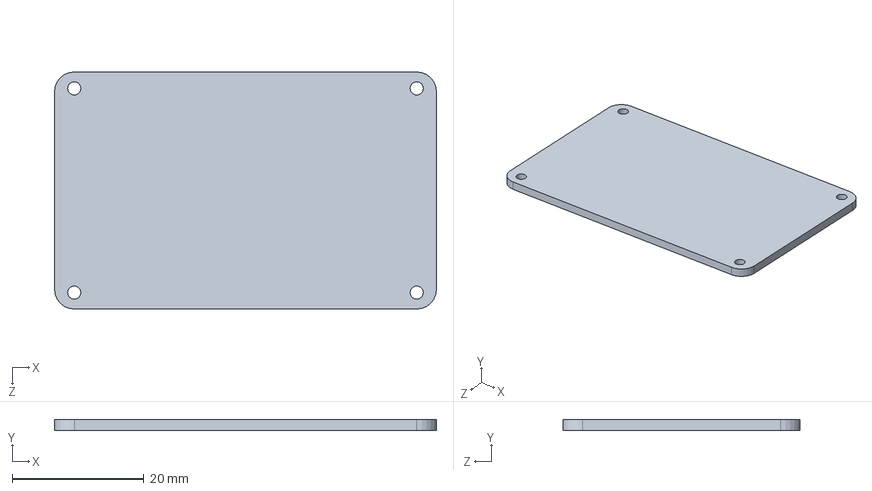
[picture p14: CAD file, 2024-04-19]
CAD/DC to DC/DC to DC PCB.SLDPRT
58.0 x 1.60 x 36.0 mm

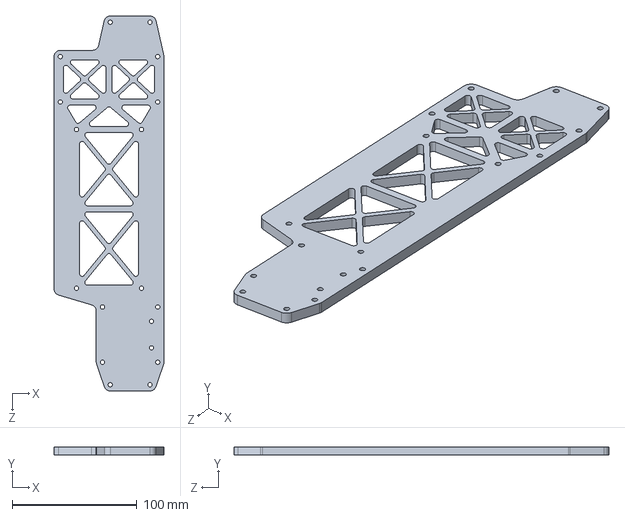
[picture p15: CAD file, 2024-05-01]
CAD/Mounting Plate.SLDPRT
88.0 x 6.35 x 300.0 mm

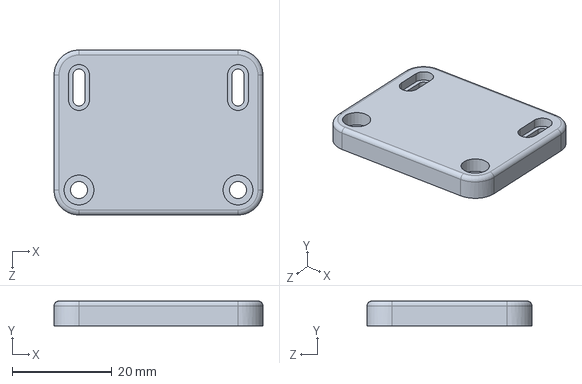
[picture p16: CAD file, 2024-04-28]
CAD/Bracket Rear.SLDPRT
41.8 x 5.00 x 33.0 mm

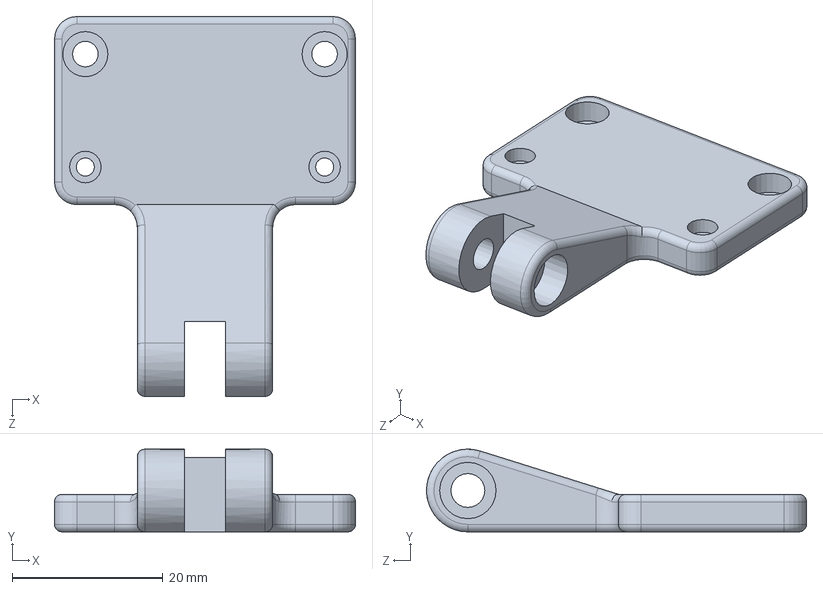
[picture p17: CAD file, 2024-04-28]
CAD/Camera/Camera Mount Base 2.SLDPRT
40.0 x 11.0 x 50.5 mm

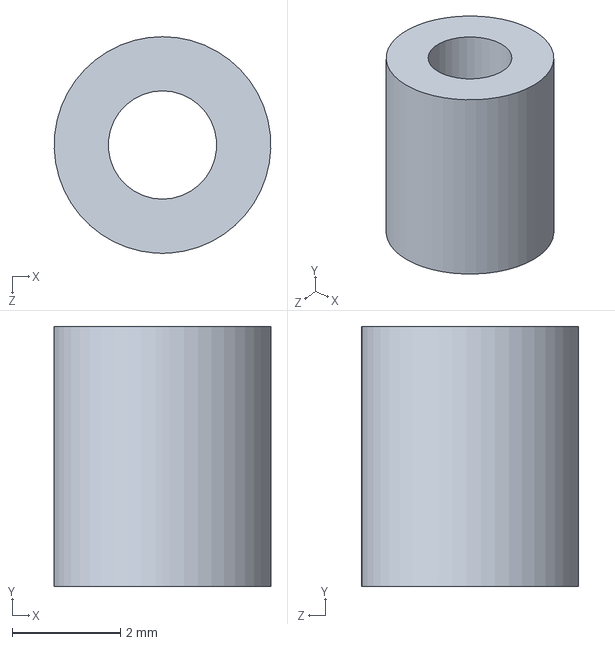
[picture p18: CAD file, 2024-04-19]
CAD/DC to DC/DC to DC Standoff.SLDPRT
4.00 x 4.80 x 4.00 mm

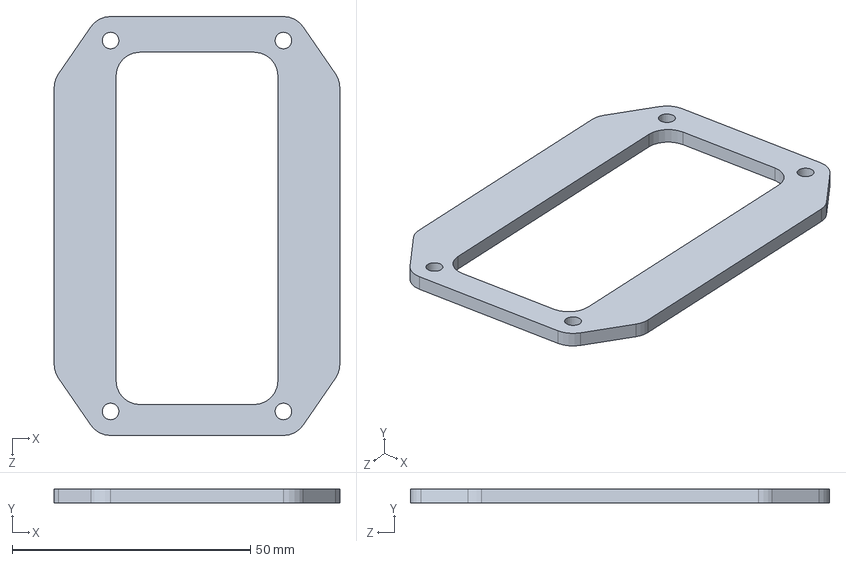
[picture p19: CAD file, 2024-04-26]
CAD/GPS/GPS Bracket.SLDPRT
60.0 x 3.00 x 88.0 mm

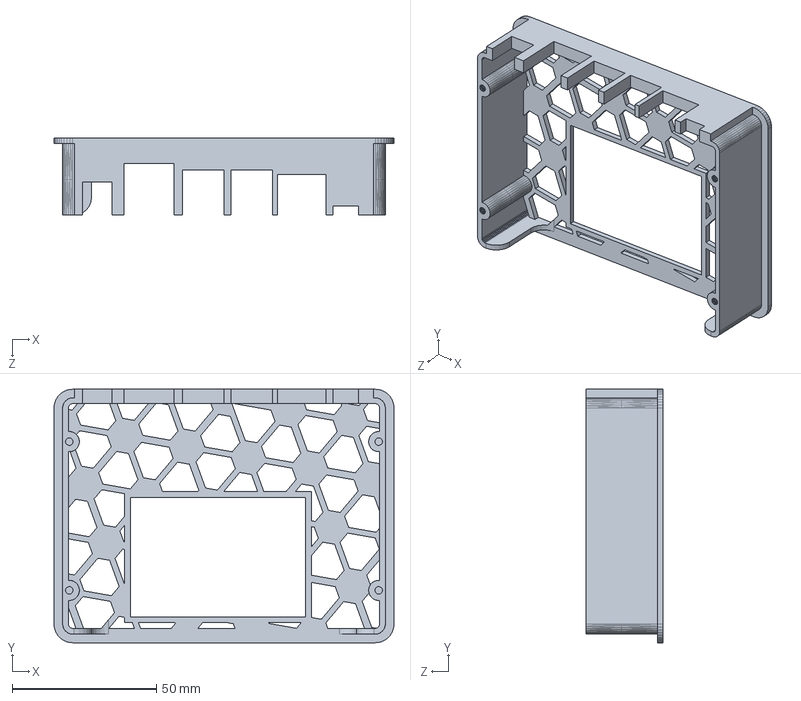
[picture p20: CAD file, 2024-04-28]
CAD/Jetson/Case Top.SLDPRT
118.0 x 88.0 x 26.8 mm

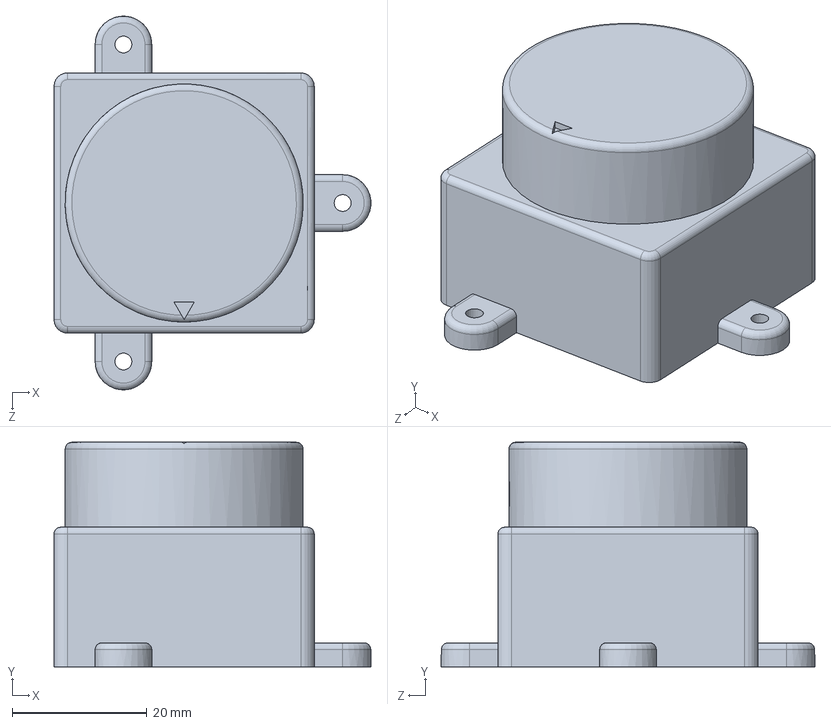
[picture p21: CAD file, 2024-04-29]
CAD/LIDAR/LIDAR.SLDPRT
47.0 x 33.3 x 55.4 mm

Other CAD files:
CAD/GPS/GPS Antenna.SLDPRT
CAD/Jetson/NanoMeshMini-Bottom-Jetson-Nano-DevKit-Case.stl
CAD/LIDAR/LIDAR Mount.SLDPRT
CAD/VESC.SLDPRT
CAD/Anti Spark Switch.SLDPRT
CAD/Battery.SLDPRT
CAD/Camera/Camera Mount Base.SLDPRT
CAD/Camera/Oak D Lite.SLDPRT
CAD/GPS/GPS.SLDPRT
CAD/Hardware/90591A265_Zinc-Plated Steel Hex Nut.SLDPRT
CAD/Hardware/90592A090_Steel Hex Nut.SLDPRT
CAD/Hardware/91290A113_Alloy Steel Socket Head Screw.SLDPRT
CAD/Hardware/91292A108_18-8 Stainless Steel Socket Head Screw.SLDPRT
CAD/Hardware/91292A118_18-8 Stainless Steel Socket Head Screw.SLDPRT
CAD/Hardware/91292A833_18-8 Stainless Steel Socket Head Screw.SLDPRT
CAD/Hardware/93655A093_Male-Female Threaded Hex Standoff.SLDPRT
CAD/Hardware/94868A176_Female Threaded Hex Standoff.SLDPRT
CAD/Hardware/94868A722_Female Threaded Hex Standoff (1).SLDPRT
CAD/Hardware/94868A722_Female Threaded Hex Standoff.SLDPRT
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

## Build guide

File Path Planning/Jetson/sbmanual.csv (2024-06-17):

0.00967964850133285 | 0.14594266237691045 | 3.051850947599719e-05
-0.03912378300447017 | -0.06642809603363276 | 0.1857966856898709
-0.055290872405748814 | -0.3250628621317446 | 0.1620685445722831
-0.07300461741397157 | -0.5781512353569269 | 0.14230780968657492
-0.20905945455888286 | -0.7663079593330622 | 0.14230780968657492
-0.26891200558748096 | -1.0396264824084938 | 0.16602069154942473
-0.32876455754740164 | -1.3129450040869415 | 0.173940244758446
-0.38860887329792604 | -1.5825682478025556 | 0.18974883266701253
-0.4421429435024038 | -1.818947886582464 | 0.23322244941557055
-1.2470245895092376 | -2.009308146312833 | 0.1857966856898709
-1.274113078485243 | -2.2716138497926295 | 0.1857966856898709
-1.4101432351162657 | -2.4486847198568285 | 0.14230780968657492
-1.5508792973705567 | -2.6386786331422627 | 0.20555742057557908
-1.6869218274368905 | -2.821292418986559 | 0.2490310373241371
-1.8867728189215995 | -2.9538773614913225 | 0.260887478255562
-2.0400428596767597 | -3.171558042988181 | 0.26483962523270366
-2.2136048631509766 | -3.4002793510444462 | 0.18974883266701253
-2.4199886763235554 | -3.6658804211765528 | 0.20555742057557908
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

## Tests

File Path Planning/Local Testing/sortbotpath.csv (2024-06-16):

0.000000000000000000e+00 | 0.000000000000000000e+00 | 0.000000000000000000e+00
-1.044735579867922814e-01 | -3.275768348225824855e-01 | 0.000000000000000000e+00
-2.049453533019044149e-01 | -6.482013239065765875e-01 | 0.000000000000000000e+00
-3.014710193921505965e-01 | -9.619507788438295126e-01 | 0.000000000000000000e+00
-3.941061922345812096e-01 | -1.268902496541301606e+00 | 0.000000000000000000e+00
-4.829065034344579566e-01 | -1.569133784956210587e+00 | 0.000000000000000000e+00
-5.679275972040188636e-01 | -1.862721948594585841e+00 | 0.000000000000000000e+00
-6.492251005524097840e-01 | -2.149744293657536609e+00 | 0.000000000000000000e+00
-7.268546511498009677e-01 | -2.430278120187634450e+00 | 0.000000000000000000e+00
-8.008718852681843137e-01 | -2.704400736492123425e+00 | 0.000000000000000000e+00
-8.713324356346311417e-01 | -2.972189443160508038e+00 | 0.000000000000000000e+00
-9.382919406758826186e-01 | -3.233721549352817526e+00 | 0.000000000000000000e+00
-1.001806034926777000e+00 | -3.489074358814384436e+00 | 0.000000000000000000e+00
-1.061930350814479285e+00 | -3.738325173500366638e+00 | 0.000000000000000000e+00
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

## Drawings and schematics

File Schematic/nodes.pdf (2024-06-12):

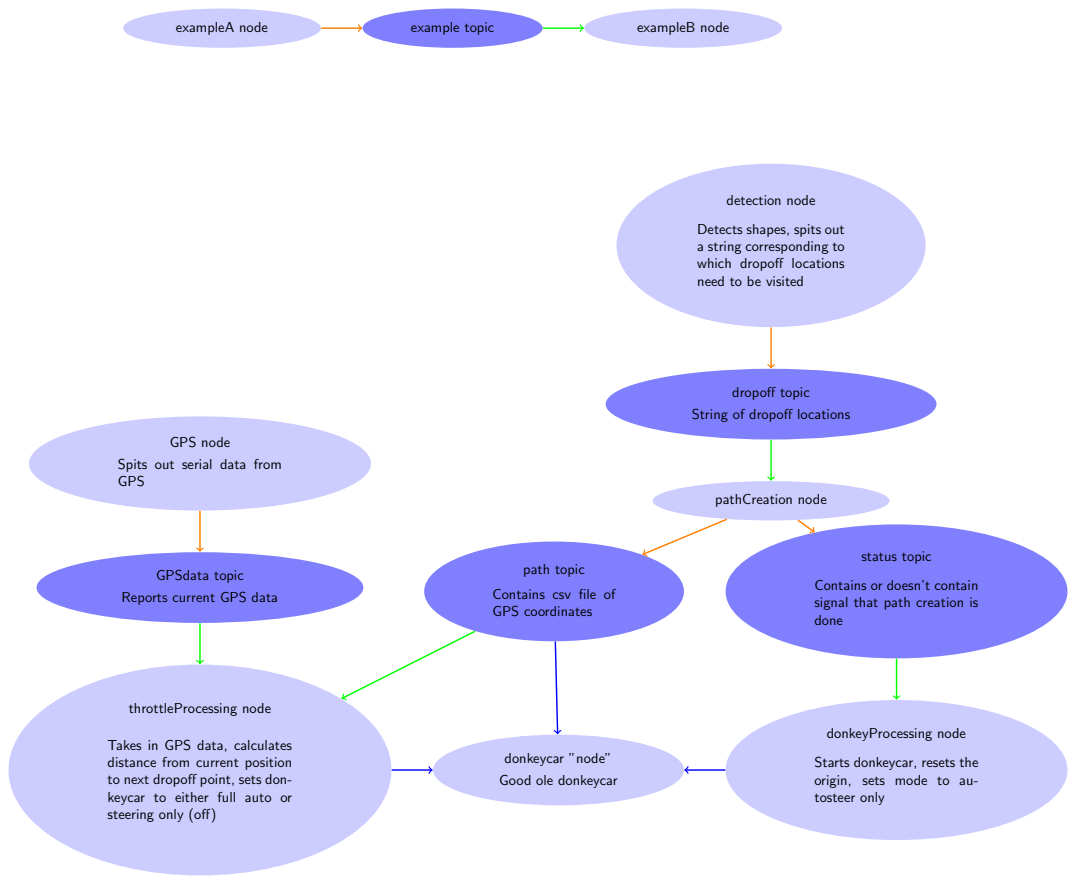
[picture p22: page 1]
exampleA node; example topic; exampleB node; detection node; dropoff topic; pathCreation node; path topic; status topic; donkeyProcessing node; throttleProcessing node; GPS node

Detects shapes, spits out
a string corresponding to
which dropoff locations
need to be visited

String of dropoff locations

Spits out serial data from
GPS

GPSdata topic
Reports current GPS data

Contains or doesn’t contain
signal that path creation is
done

Contains csv file of
GPS coordinates

Takes in GPS data, calculates
distance from current position
to next dropoff point, sets don-
keycar to either full auto or
steering only (off)

donkeycar ”node”
Good ole donkeycar

Starts donkeycar, resets the
origin, sets mode to au-
tosteer only

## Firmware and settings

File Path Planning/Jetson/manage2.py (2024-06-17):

#!/usr/bin/env python3
"""
Scripts to record a path by driving a donkey car
and using an autopilot to drive the recoded path.
Works with wheel encoders and/or Intel T265

Usage:
    manage.py (drive) [--js] [--log=INFO] [--camera=(single|stereo)]
 

Options:
    -h --help          Show this screen.
    --js               Use physical joystick.
    -f --file=<file>   A text file containing paths to tub files, one per line. Option may be used more than once.
    --meta=<key:value> Key/Value strings describing describing a piece of meta data about this drive. Option may be used more than once.

Starts in user mode.
- The user flow to 'train' a path.   
  - start "python manage.py drive" 
  - This starts in user mode; so user is in manual drive mode 
    driving records path waypoints.
  - drive to record a path; make the start and end close to each other.
  - if you don't like path, select the reset button and it will
    reset the origin _AND_ erase the path from memory.  MOve the
    vehicle back to where the physical origin is and start driving
    again to record a new path.
  - if you like the path, select the save button to save it. 
- The user flow for autopilot:  
  - record or load a path (select load button) 
  - select auto-pilot mode using joystick or web ui.  The
    vehicle will start trying to follow the recorded path.
  - switch back user model to stop autopilot.
  - to restart using the saved path; 
    - select reset button; this will erase path and reset origin 
    - select load button to load path
    - put the car back at the physical origin.


"""
from distutils.log import debug
import os
import logging

#
# import cv2 early to avoid issue with importing after tensorflow
# see https://github.com/opencv/opencv/issues/14884#issuecomment-599852128
#
import time

try:
    import cv2
except:
    pass


from docopt import docopt

import donkeycar as dk
from donkeycar.parts import actuator
from donkeycar.parts.controller import JoystickController
from donkeycar.parts.path import CsvThrottlePath, PathPlot, CTE, PID_Pilot, \
    PlotCircle, PImage, OriginOffset
from donkeycar.parts.transform import PIDController
from donkeycar.parts.kinematics import TwoWheelSteeringThrottle
from donkeycar.templates.complete import add_odometry, add_camera, \
    add_user_controller, add_drivetrain, add_simulator, add_imu, DriveMode, \
    UserPilotCondition, ToggleRecording
from donkeycar.parts.logger import LoggerPart
from donkeycar.parts.transform import Lambda
from donkeycar.parts.explode import ExplodeDict

logger = logging.getLogger(__name__)
logging.basicConfig(level=logging.INFO)

def drive(cfg, use_joystick=False, camera_type='single'):
    '''
    Construct a working robotic vehicle from many parts.
    Each part runs as a job in the Vehicle loop, calling either
    it's run or run_threaded method depending on the constructor flag
    `threaded`.  All parts are updated one after another at the framerate given
    in cfg.DRIVE_LOOP_HZ assuming each part finishes processing in a timely
    manner. Parts may have named outputs and inputs. The framework handles
    passing named outputs to parts requesting the same named input.
    '''

    is_differential_drive = cfg.DRIVE_TRAIN_TYPE.startswith("DC_TWO_WHEEL")

    #Initialize car
    V = dk.vehicle.Vehicle()

    if cfg.HAVE_SOMBRERO:
        from donkeycar.utils import Sombrero
        s = Sombrero()
   
    #Initialize logging before anything else to allow console logging
    if cfg.HAVE_CONSOLE_LOGGING:
        logger.setLevel(logging.getLevelName(cfg.LOGGING_LEVEL))
        ch = logging.StreamHandler()
        ch.setFormatter(logging.Formatter(cfg.LOGGING_FORMAT))
        logger.addHandler(ch)

    if cfg.HAVE_MQTT_TELEMETRY:
        from donkeycar.parts.telemetry import MqttTelemetry
        tel = MqttTelemetry(cfg)

    #
    # if we are using the simulator, set it up
    #
    add_simulator(V, cfg)

    #
    # IMU
    #
    add_imu(V, cfg)

    #
    # odometry/tachometer/speed control
    #
    if cfg.HAVE_ODOM:
        #
        # setup encoders, odometry and pose estimation
        #
        add_odometry(V, cfg)
    else:
        # we give the T265 no calib to indicated we don't have odom
        cfg.WHEEL_ODOM_CALIB = None

        #This dummy part to satisfy input needs of RS_T265 part.
        class NoOdom():
            def run(self):
                return 0.0

        V.add(NoOdom(), outputs=['enc/vel_m_s'])

    if cfg.HAVE_T265:
        from donkeycar.parts.realsense2 import RS_T265
        if cfg.HAVE_ODOM and not os.path.exists(cfg.WHEEL_ODOM_CALIB):
            print("You must supply a json file when using odom with T265. "
                  "There is a sample file in templates.")
            print("cp donkeycar/donkeycar/templates/calibration_odometry.json .")
            exit(1)

        #
        # NOTE: image output on the T265 is broken in the python API and
        #       will never get fixed, so not image output from T265
        #
        rs = RS_T265(image_output=False, calib_filename=cfg.WHEEL_ODOM_CALIB, device_id=cfg.REALSENSE_T265_ID)
        V.add(rs, inputs=['enc/vel_m_s'], outputs=['rs/pos', 'rs/vel', 'rs/acc'], threaded=True)

        #
        # Pull out the realsense T265 position stream, output 2d coordinates we can use to map.
        # Transform the T265 augmented reality coordinate system into a traditional
        # top-down POSE coordinate system where east is positive-x and north is positive-y.
        #
        class PosStream:
            def run(self, pos):
                #y is up, x is right, z is backwards/forwards (negative going forwards)
                return -pos.z, -pos.x

        V.add(PosStream(), inputs=['rs/pos'], outputs=['pos/x', 'pos/y'])

    #
    # gps outputs ['pos/x', 'pos/y']
    #
    gps_player = add_gps(V, cfg)

    #
    # setup primary camera
    #
    add_camera(V, cfg, camera_type)

    #
    # add the user input controller(s)
    # - this will add the web controller
    # - it will optionally add any configured 'joystick' controller
    #
    has_input_controller = hasattr(cfg, "CONTROLLER_TYPE") and cfg.CONTROLLER_TYPE != "mock"
    ctr = add_user_controller(V, cfg, use_joystick, input_image = 'map/image')

    #
    # explode the web buttons into their own key/values in memory
    #
    V.add(ExplodeDict(V.mem, "web/"), inputs=['web/buttons'])

    #
    # This part will reset the car back to the origin. You must put the car in the known origin
    # and push the cfg.RESET_ORIGIN_BTN on your controller. This will allow you to induce an offset
    # in the mapping.
    #
    origin_reset = OriginOffset(cfg.PATH_DEBUG)
    V.add(origin_reset, inputs=['pos/x', 'pos/y', 'cte/closest_pt'], outputs=['pos/x', 'pos/y', 'cte/closest_pt'])


    #
    # maintain run conditions for user mode and autopilot mode parts.
    #
    V.add(UserPilotCondition(),
          inputs=['user/mode', "cam/image_array", "cam/image_array"],
          outputs=['run_user', "run_pilot", "ui/image_array"])


    # This is the path object. It will record a path when distance changes and it travels
    # at least cfg.PATH_MIN_DIST meters. Except when we are in follow mode, see below...
    path = CsvThrottlePath(min_dist=cfg.PATH_MIN_DIST)
    V.add(path, inputs=['recording', 'pos/x', 'pos/y', 'user/throttle'], outputs=['path', 'throttles'])

    #
    # log pose
    #
    # if cfg.DONKEY_GYM:
    #     lpos = LoggerPart(inputs=['dist/left', 'dist/right', 'dist', 'pos/pos_x', 'pos/pos_y', 'yaw'], level="INFO", logger="simulator")
    #     V.add(lpos, inputs=lpos.inputs)
    # if cfg.HAVE_ODOM:
    #     if cfg.HAVE_ODOM_2:
    #         lpos = LoggerPart(inputs=['enc/left/distance', 'enc/right/distance', 'enc/left/timestamp', 'enc/right/timestamp'], level="INFO", logger="odometer")
    #         # V.add(lpos, inputs=lpos.inputs)
    #     lpos = LoggerPart(inputs=['enc/distance', 'enc/timestamp'], level="INFO", logger="odometer")
    #     V.add(lpos, inputs=lpos.inputs)
    #     lpos = LoggerPart(inputs=['pos/x', 'pos/y', 'pos/steering'], level="INFO", logger="kinematics")
    #     V.add(lpos, inputs=lpos.inputs)

    def save_path():
        if path.length() > 0:
            if path.save(cfg.PATH_FILENAME):
                print("That path was saved to ", cfg.PATH_FILENAME)

                # save any recorded gps readings
                if gps_player:
                    gps_player.nmea.save()
            else:
                print("The path could NOT be saved; check the PATH_FILENAME in myconfig.py to make sure it is a legal path")
        else:
            print("There is no path to save; try recording the path.")

    def load_path():
        if os.path.exists(cfg.PATH_FILENAME) and path.load(cfg.PATH_FILENAME):
           print("The path was loaded was loaded from ", cfg.PATH_FILENAME)

           # we loaded the path; also load any recorded gps readings
           if gps_player:
               gps_player.stop().nmea.load()
               gps_player.start()
        else:
           print("path _not_ loaded; make sure you have saved a path.")

    def erase_path():
        origin_reset.reset_origin()
        if path.reset():
            print("The origin and the path were reset; you are ready to record a new path.")
            if gps_player:
                gps_player.stop().nmea.reset()
        else:
            print("The origin was reset; you are ready to record a new path.")

    def reset_origin():
        """
        Reset effective pose to (0, 0)
        """
        origin_reset.reset_origin()
        print("The origin was reset to the current position.")

        # restart any recorded gps readings from the start.
        if gps_player:
            gps_player.start()


    # When a path is loaded, we will be in follow mode. We will not record.
    if os.path.exists(cfg.PATH_FILENAME):
        load_path()

    # Here's an image we can map to.
    img = PImage(clear_each_frame=True)
    V.add(img, outputs=['map/image'])

    # This PathPlot will draw path on the image

    plot = PathPlot(scale=cfg.PATH_SCALE, offset=cfg.PATH_OFFSET)
    V.add(plot, inputs=['map/image', 'path'], outputs=['map/image'])

    # This will use path and current position to output cross track error
    cte = CTE(look_ahead=cfg.PATH_LOOK_AHEAD, look_behind=cfg.PATH_LOOK_BEHIND, num_pts=cfg.PATH_SEARCH_LENGTH)
    V.add(cte, inputs=['path', 'pos/x', 'pos/y', 'cte/closest_pt'], outputs=['cte/error', 'cte/closest_pt'], run_condition='run_pilot')

    # This will use the cross track error and PID constants to try to steer back towards the path.
    pid = PIDController(p=cfg.PID_P, i=cfg.PID_I, d=cfg.PID_D)
    pilot = PID_Pilot(pid, cfg.PID_THROTTLE, cfg.USE_CONSTANT_THROTTLE, min_throttle=cfg.PID_THROTTLE)
    V.add(pilot, inputs=['cte/error', 'throttles', 'cte/closest_pt'], outputs=['pilot/steering', 'pilot/throttle'], run_condition="run_pilot")

    def dec_pid_d():
        pid.Kd -= cfg.PID_D_DELTA
        logging.info("pid: d- %f" % pid.Kd)

    def inc_pid_d():
        pid.Kd += cfg.PID_D_DELTA
        logging.info("pid: d+ %f" % pid.Kd)

    def dec_pid_p():
        pid.Kp -= cfg.PID_P_DELTA
        logging.info("pid: p- %f" % pid.Kp)

    def inc_pid_p():
        pid.Kp += cfg.PID_P_DELTA
        logging.info("pid: p+ %f" % pid.Kp)


    recording_control = ToggleRecording(cfg.AUTO_RECORD_ON_THROTTLE, cfg.RECORD_DURING_AI)
    V.add(recording_control, inputs=['user/mode', "recording"], outputs=["recording"])


    #
    # Add buttons for handling various user actions
    # The button names are in configuration.
    # They may refer to game controller (joystick) buttons OR web ui buttons
    #
    # There are 5 programmable webui buttons, "web/w1" to "web/w5"
    # adding a button handler for a webui button
    # is just adding a part with a run_condition set to
    # the button's name, so it runs when button is pressed.
    #
    have_joystick = ctr is not None and isinstance(ctr, JoystickController)

    # Here's a trigger to save the path. Complete one circuit of your course, when you
    # have exactly looped, or just shy of the loop, then save the path and shutdown
    # this process. Restart and the path will be loaded.
    if cfg.SAVE_PATH_BTN:
        print(f"Save path button is {cfg.SAVE_PATH_BTN}")
        if cfg.SAVE_PATH_BTN.startswith("web/w"):
            V.add(Lambda(lambda: save_path()), run_condition=cfg.SAVE_PATH_BTN)
        elif have_joystick:
            ctr.set_button_down_trigger(cfg.SAVE_PATH_BTN, save_path)

    # allow controller to (re)load the path
    if cfg.LOAD_PATH_BTN:
        print(f"Load path button is {cfg.LOAD_PATH_BTN}")
        if cfg.LOAD_PATH_BTN.startswith("web/w"):
            V.add(Lambda(lambda: load_path()), run_condition=cfg.LOAD_PATH_BTN)
        elif have_joystick:
            ctr.set_button_down_trigger(cfg.LOAD_PATH_BTN, load_path)

    # Here's a trigger to erase a previously saved path.
    # This erases the path in memory; it does NOT erase any saved path file
    if cfg.ERASE_PATH_BTN:
        print(f"Erase path button is {cfg.ERASE_PATH_BTN}")
        if cfg.ERASE_PATH_BTN.startswith("web/w"):
            V.add(Lambda(lambda: erase_path()), run_condition=cfg.ERASE_PATH_BTN)
        elif have_joystick:
            ctr.set_button_down_trigger(cfg.ERASE_PATH_BTN, erase_path)

    # Here's a trigger to reset the origin based on the current position
    if cfg.RESET_ORIGIN_BTN:
        print(f"Reset origin button is {cfg.RESET_ORIGIN_BTN}")
        if cfg.RESET_ORIGIN_BTN.startswith("web/w"):
            V.add(Lambda(lambda: reset_origin()), run_condition=cfg.RESET_ORIGIN_BTN)
        elif have_joystick:
            ctr.set_button_down_trigger(cfg.RESET_ORIGIN_BTN, reset_origin)

    # button to toggle recording
    if cfg.TOGGLE_RECORDING_BTN:
        print(f"Toggle recording button is {cfg.TOGGLE_RECORDING_BTN}")
        if cfg.TOGGLE_RECORDING_BTN.startswith("web/w"):
            V.add(Lambda(lambda: recording_control.toggle_recording()), run_condition=cfg.TOGGLE_RECORDING_BTN)
        elif have_joystick:
            ctr.set_button_down_trigger(cfg.TOGGLE_RECORDING_BTN, recording_control.toggle_recording)

    # Buttons to tune PID constants
    if cfg.DEC_PID_P_BTN and cfg.PID_P_DELTA:
        print(f"Decrement PID P button is {cfg.DEC_PID_P_BTN}")
        if cfg.DEC_PID_P_BTN.startswith("web/w"):
            V.add(Lambda(lambda: dec_pid_p()), run_condition=cfg.DEC_PID_P_BTN)
        elif have_joystick:
            ctr.set_button_down_trigger(cfg.DEC_PID_P_BTN, dec_pid_p)
    if cfg.INC_PID_P_BTN and cfg.PID_P_DELTA:
        print(f"Increment PID P button is {cfg.INC_PID_P_BTN}")
        if cfg.INC_PID_P_BTN.startswith("web/w"):
            V.add(Lambda(lambda: inc_pid_p()), run_condition=cfg.INC_PID_P_BTN)
        elif have_joystick:
            ctr.set_button_down_trigger(cfg.INC_PID_P_BTN, inc_pid_p)
    if cfg.DEC_PID_D_BTN and cfg.PID_D_DELTA:
        print(f"Decrement PID D button is {cfg.DEC_PID_D_BTN}")
        if cfg.DEC_PID_D_BTN.startswith("web/w"):
            V.add(Lambda(lambda: dec_pid_d()), run_condition=cfg.DEC_PID_D_BTN)
        elif have_joystick:
            ctr.set_button_down_trigger(cfg.DEC_PID_D_BTN, dec_pid_d)
    if cfg.INC_PID_D_BTN and cfg.PID_D_DELTA:
        print(f"Increment PID D button is {cfg.INC_PID_D_BTN}")
        if cfg.INC_PID_D_BTN.startswith("web/w"):
            V.add(Lambda(lambda: inc_pid_d()), run_condition=cfg.INC_PID_D_BTN)
        elif have_joystick:
            ctr.set_button_down_trigger(cfg.INC_PID_D_BTN, inc_pid_d)


    #
    # Decide what inputs should change the car's steering and throttle
    # based on the choice of user or autopilot drive mode
    #
    V.add(DriveMode(cfg.AI_THROTTLE_MULT),
          inputs=['user/mode', 'user/steering', 'user/throttle',
                  'pilot/steering', 'pilot/throttle'],
          outputs=['steering', 'throttle'])

    # V.add(LoggerPart(['user/mode', 'steering', 'throttle'], logger="drivemode"), inputs=['user/mode', 'steering', 'throttle'])

    #
    # To make differential drive steer,
    # divide throttle between motors based on the steering value
    #
    if is_differential_drive:
        V.add(TwoWheelSteeringThrottle(),
            inputs=['throttle', 'steering'],
            outputs=['left/throttle', 'right/throttle'])

    #
    # Setup drivetrain
    #
    add_drivetrain(V, cfg)


    #
    # OLED display setup
    #
    if cfg.USE_SSD1306_128_32:
        from donkeycar.parts.oled import OLEDPart
        auto_record_on_throttle = cfg.USE_JOYSTICK_AS_DEFAULT and cfg.AUTO_RECORD_ON_THROTTLE
        oled_part = OLEDPart(cfg.SSD1306_128_32_I2C_ROTATION, cfg.SSD1306_RESOLUTION, auto_record_on_throttle)
        V.add(oled_part, inputs=['recording', 'tub/num_records', 'user/mode'], outputs=[], threaded=True)


    # Print Joystick controls
    if ctr is not None and isinstance(ctr, JoystickController):
        ctr.print_controls()

    #
    # draw a map image as the vehicle moves
    #
    loc_plot = PlotCircle(scale=cfg.PATH_SCALE, offset=cfg.PATH_OFFSET, color = "blue")
    V.add(loc_plot, inputs=['map/image', 'pos/x', 'pos/y'], outputs=['map/image'], run_condition='run_pilot')

    loc_plot = PlotCircle(scale=cfg.PATH_SCALE, offset=cfg.PATH_OFFSET, color = "green")
    V.add(loc_plot, inputs=['map/image', 'pos/x', 'pos/y'], outputs=['map/image'], run_condition='run_user')


    V.start(rate_hz=cfg.DRIVE_LOOP_HZ, 
        max_loop_count=cfg.MAX_LOOPS)


def add_gps(V, cfg):
    if cfg.HAVE_GPS:
        from donkeycar.parts.serial_port import SerialPort, SerialLineReader
        from donkeycar.parts.gps import GpsNmeaPositions, GpsLatestPosition, GpsPlayer
        from donkeycar.parts.pipe import Pipe
        from donkeycar.parts.text_writer import CsvLogger

        #
        # parts to
        # - read nmea lines from serial port
        # - OR play from recorded file
        # - convert nmea lines to positions
        # - retrieve the most recent position
        #
        serial_port = SerialPort(cfg.GPS_SERIAL, cfg.GPS_SERIAL_BAUDRATE)
        nmea_reader = SerialLineReader(serial_port)
        V.add(nmea_reader, outputs=['gps/nmea'], threaded=True)

        # part to save nmea sentences for later playback
        nmea_player = None
        if cfg.GPS_NMEA_PATH:
            nmea_writer = CsvLogger(cfg.GPS_NMEA_PATH, separator='\t', field_count=2)
            V.add(nmea_writer, inputs=['recording', 'gps/nmea'], outputs=['gps/recorded/nmea'])  # only record nmea sentences in user mode
            nmea_player = GpsPlayer(nmea_writer)
            V.add(nmea_player, inputs=['run_pilot', 'gps/nmea'], outputs=['gps/playing', 'gps/nmea'])  # only play nmea sentences in autopilot mode

        gps_positions = GpsNmeaPositions(debug=cfg.GPS_DEBUG)
        V.add(gps_positions, inputs=['gps/nmea'], outputs=['gps/positions'])
        gps_latest_position = GpsLatestPosition(debug=cfg.GPS_DEBUG)
        V.add(gps_latest_position, inputs=['gps/positions'], outputs=['gps/timestamp', 'gps/utm/longitude', 'gps/utm/latitude'])

        # rename gps utm position to pose values
        V.add(Pipe(), inputs=['gps/utm/longitude', 'gps/utm/latitude'], outputs=['pos/x', 'pos/y'])

        return nmea_player


if __name__ == '__main__':
    args = docopt(__doc__)
    cfg = dk.load_config()

    log_level = args['--log'] or "INFO"
    numeric_level = getattr(logging, log_level.upper(), None)
    if not isinstance(numeric_level, int):
        raise ValueError('Invalid log level: %s' % log_level)
    logging.basicConfig(level=numeric_level)


    if args['drive']:
        drive(cfg, use_joystick=args['--js'], camera_type=args['--camera'])

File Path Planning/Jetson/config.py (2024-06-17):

"""
PATH FOLLOWING: 'path_follow' template configurations

# This file is read by your car application's manage.py script to change the car
# performance

# If desired, all config overrides can be specified here. 
# The update operation will not touch this file.
# """

import os


import os

#
# FILE PATHS
#
CAR_PATH = PACKAGE_PATH = os.path.dirname(os.path.realpath(__file__))
DATA_PATH = os.path.join(CAR_PATH, 'data')
MODELS_PATH = os.path.join(CAR_PATH, 'models')


#
# VEHICLE loop
#
DRIVE_LOOP_HZ = 20      # the vehicle loop will pause if faster than this speed.
MAX_LOOPS = None        # the vehicle loop can abort after this many iterations, when given a positive integer.


#
# CAMERA configuration
#
CAMERA_TYPE = "PICAM"   # (PICAM|WEBCAM|CVCAM|CSIC|V4L|D435|MOCK|IMAGE_LIST)
IMAGE_W = 160
IMAGE_H = 120
IMAGE_DEPTH = 3         # default RGB=3, make 1 for mono
CAMERA_FRAMERATE = DRIVE_LOOP_HZ
CAMERA_VFLIP = False
CAMERA_HFLIP = False
CAMERA_INDEX = 0  # used for 'WEBCAM' and 'CVCAM' when there is more than one camera connected
# For CSIC camera - If the camera is mounted in a rotated position, changing the below parameter will correct the output frame orientation
CSIC_CAM_GSTREAMER_FLIP_PARM = 0 # (0 => none , 4 => Flip horizontally, 6 => Flip vertically)
BGR2RGB = False  # true to convert from BRG format to RGB format; requires opencv

# For IMAGE_LIST camera
PATH_MASK = "~/mycar/data/tub_1_20-03-12/*.jpg"


#
# PCA9685, over rides only if needed, ie. TX2..
#
PCA9685_I2C_ADDR = 0x40     #I2C address, use i2cdetect to validate this number
PCA9685_I2C_BUSNUM = None   #None will auto detect, which is fine on the pi. But other platforms should specify the bus num.


#
# SSD1306_128_32
#
USE_SSD1306_128_32 = False    # Enable the SSD_1306 OLED Display
SSD1306_128_32_I2C_ROTATION = 0 # 0 = text is right-side up, 1 = rotated 90 degrees clockwise, 2 = 180 degrees (flipped), 3 = 270 degrees
SSD1306_RESOLUTION = 1 # 1 = 128x32; 2 = 128x64


#
# MEASURED ROBOT PROPERTIES
#
AXLE_LENGTH = 0.03     # length of axle; distance between left and right wheels in meters
WHEEL_BASE = 0.1       # distance between front and back wheels in meters
WHEEL_RADIUS = 0.0315  # radius of wheel in meters
MIN_SPEED = 0.1        # minimum speed in meters per second; speed below which car stalls
MAX_SPEED = 3.0        # maximum speed in meters per second; speed at maximum throttle (1.0)
MIN_THROTTLE = 0.1     # throttle (0 to 1.0) that corresponds to MIN_SPEED, throttle below which car stalls
MAX_STEERING_ANGLE = 3.141592653589793 / 4  # for car-like robot; maximum steering angle in radians (corresponding to tire angle at steering == -1)


#
# DRIVE_TRAIN_TYPE
# These options specify which chasis and motor setup you are using.
# See Actuators documentation https://docs.donkeycar.com/parts/actuators/
# for a detailed explanation of each drive train type and it's configuration.
# Choose one of the following and then update the related configuration section:
#
# "PWM_STEERING_THROTTLE" uses two PWM output pins to control a steering servo and an ESC, as in a standard RC car.
# "MM1" Robo HAT MM1 board
# "SERVO_HBRIDGE_2PIN" Servo for steering and HBridge motor driver in 2pin mode for motor
# "SERVO_HBRIDGE_3PIN" Servo for steering and HBridge motor driver in 3pin mode for motor
# "DC_STEER_THROTTLE" uses HBridge pwm to control one steering dc motor, and one drive wheel motor
# "DC_TWO_WHEEL" uses HBridge in 2-pin mode to control two drive motors, one on the left, and one on the right.
# "DC_TWO_WHEEL_L298N" using HBridge in 3-pin mode to control two drive motors, one of the left and one on the right.
# "MOCK" no drive train.  This can be used to test other features in a test rig.
# (deprecated) "SERVO_HBRIDGE_PWM" use ServoBlaster to output pwm control from the PiZero directly to control steering,
#                                  and HBridge for a drive motor.
# (deprecated) "PIGPIO_PWM" uses Raspberrys internal PWM
# (deprecated) "I2C_SERVO" uses PCA9685 servo controller to control a steering servo and an ESC, as in a standard RC car
#
DRIVE_TRAIN_TYPE = "PWM_STEERING_THROTTLE"
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

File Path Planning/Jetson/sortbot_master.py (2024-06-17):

from roboflowoak import RoboflowOak
import cv2
import time
import numpy as np
from pathPlanning import pathPlanning
from functions import plotEnvironment
from pathConfig import angle, origin, dropoff, obstacle, offset, cardyn

# OOP
def main(args=None):

  print('Object detection process has started!')
  # Define confidence target
  confidence_targ = 0.85
  
  # Initialize roboflow model
  rf = RoboflowOak(model="mae-148-cv", confidence=0.05, overlap=0.5, version="1", api_key="Kq55iT9KOAwtcOUiZV9Z", rgb=True, depth=True, device=None, blocking=True)
  # Initialize empty variables
  confidence_curr = 0
  object_recog = ''
  while confidence_curr <= np.float64(confidence_targ):
    # Running our model and displaying the video output with detections
    t0 = time.time()
    # The rf.detect() function runs the model inference
    result, frame, raw_frame, depth = rf.detect()
    predictions = result["predictions"]
    #{
    #    predictions:
    #    [ {
    #        x: (middle),
    #        y:(middle),
    #        width:
    #        height:
    #        depth: ###->
    #        confidence:
    #        class:
    #        mask: {
    #    ]
    #}
    #frame - frame after preprocs, with predictions
    #raw_frame - original frame from your OAK
    #depth - depth map for raw_frame, center-rectified to the center camera
    
    # timing: for benchmarking purposes
    t = time.time()-t0
    
    # displaying the video feed as successive frames
    #cv2.imshow("frame", frame)
    
    if predictions:
      confidence_curr = predictions[0].confidence
      print("PREDICTIONS ", predictions[0].json())
      object_recog = predictions[0].class_name
      
  # Generate path
  GPS, interp, path_local = pathPlanning(angle(), origin(), np.array([0, 0]), dropoff(object_recog), obstacle(), offset(), cardyn())
    
  # Convert the coords to csv and stor in desired path
  file_path = "/home/jetson/projects/mycar/sortbotpath.csv"
  np.savetxt(file_path, GPS, delimiter=", ", fmt='%f')
  print('Path created succesfully!')
  
  time.sleep(5)

# Allow for call directly from command line (not necessary)
if __name__ == '__main__':
  main()

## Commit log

2024-04-19 Initial push
    [90591A265_Zinc-Plated Steel Hex Nut.SLDPRT, 90592A090_Steel Hex Nut.SLDPRT, 91292A108_18-8 Stainless Steel Socket Head Screw.SLDPRT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]
2024-04-19 Removed some unused files
    [94868A166_Female Threaded Hex Standoff.SLDPRT]
2024-04-24 Added schematic, organized CAD files into folder
    [90591A265_Zinc-Plated Steel Hex Nut.SLDPRT, 90592A090_Steel Hex Nut.SLDPRT, 91292A108_18-8 Stainless Steel Socket Head Screw.SLDPRT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]
2024-04-26 I forgot to fetch origin
    [91290A113_Alloy Steel Socket Head Screw.SLDPRT, 93655A093_Male-Female Threaded Hex Standoff.SLDPRT, 94868A176_Female Threaded Hex Standoff.SLDPRT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]
2024-04-28 Started SD card slot addtion on Jetson, printed parts
    [Body1.SLDPRT, Body2.SLDPRT, Bracket Rear.SLDPRT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]
2024-04-28 OrcaSlicer layout
    [Camera Mount Base 2.3mf]
2024-04-28 More printing
    [Body1.SLDPRT, Body2.SLDPRT, LIDAR Assembly.SLDASM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]
2024-04-28 More prints
    [Bracket Rear.SLDPRT, Bracket Rear.STL, Camera Assembly.SLDASM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]
2024-04-28 Tried pocketing
    [Mounting Plate 2.SLDPRT]
2024-04-29 Updated LIDAR
    [LIDAR Assembly.SLDASM, LIDAR.SLDPRT]
2024-05-01 Updated pocketing
    [Body1.SLDPRT, Body2.SLDPRT, Mounting Plate 2.SLDPRT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]
2024-05-28 Progress
    - Final collision check not implemented bc it needs to be optimized
    - Plotting functions likely buggy
    - WGS84 conversion seems really sketchy
    [functions.py, pathPlanning.py]
2024-05-30 More progress
    - Plotting works
    - Testing collision in test.py
    [functions.py, pathPlanning.py]
2024-05-30 More progress
    - Shortest path calculation is working
    - Need to implement collision detection
    [functions.py, pathPlanning.py]
2024-05-31 Updates!
    - Collision checking only happens after the permutations due to recursion limitations, not sure how to fix this
    - Spline interpolation seems to not work at all
    - Not sure if GPS works
    [functions.py, geometry.py, pathPlanning.py]
2024-05-31 Almost done
    - GPS conversion works
    - spline interpolation works
    - still have the collision checking limitation, not sure on that
    - otherwise this is done
    [functions.py, geometry.py, pathPlanning.py]
2024-06-14 Distnace based interpolation
    [sortbotpath.csv]
2024-06-16 Final :D
    [sortbotpath.csv]
2024-06-17 File organization
    [Bracket Rear.STL, Camera Mount Base 2.STL, Camera Mount Plate.STL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]
